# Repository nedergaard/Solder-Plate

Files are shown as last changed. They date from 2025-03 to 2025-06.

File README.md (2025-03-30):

🚀 This is a fork of [arwidcool/Solder-Plate](https://github.com/arwidcool/Solder-Plate). Please contribute to the original repository instead of this one.

---

# Solder Plate Controller with Detachable Hotplate

This repository contains the source code and design files for a Solder Plate Controller and detachable hotplate. The processor used is the ATmega4809 and is based on the work of DerSpatz. https://github.com/DerSpatz/PCB-reflow-solder-heat-plate

## Features
- Precise temperature control for soldering SMD components. with support of **up to 6 thermistors**.
- Cheap and widely available MCU- Atmega4809 and low BOM cost
- Custom PCB design with 2 versions: single area control (Completed) and 4 independent heating zones control(In works)
- Detacabale hotplate allows for use of new heatplate designs including larger ones
- Programming via USB
- PlatformIO integration for streamlined development.
- wifi via esp8266-12f module (with wifi version - In Development).
- Based on Reflow Hotplate by DerSpatz with some improvements
- Oled for menu navigation, debugging, and thermistor info
- TFT for reflow profile target and actual temp
- 4 buttons for menu navigation
- Current sense IC for current monitoring
- 3 indicator LED's. They work for both menu and REFLOW profiles (blinking while on the current stage and solid once the profile stage is complete).
- Buzzer for complete notification
- Buck- Converter for input voltage, allowing up to 24V in
- 24V+ rated input voltage stage components allowing  up to 24V to be used (Depending on powersupply trip option the "max" pwm needs to be lowered to not trip power suppply safety)
- Optional fan for cooling stage (not yet installed)
= Included are files for a case and a guard for the detachable plate terminal guard.





## Getting Started

### Prerequisites

- PlatformIO Core or PlatformIO IDE.
- ATmega4809 microcontroller and all the BOM components
- Basic soldering tools and electronic assembly skills.
- Access to a PCB manufacturing service or soldering equipment (solder paste, hot air gun, tweezers)
- Some basic technical skills

### Hardware Setup

*** MAKE SURE YOU ORDER THE HOTPLATE IN BLACK. IT WILL NOT DISCOLOR AND HOLDS UP A LOT BETTER TO HEAT CYCLES ***

1. **PCB Fabrication:** Fabricate the PCB using the provided gerber files. You can use these to order the naked PCB from services like JLCPCB. 
2. **Component Assembly:** Solder the components onto the PCB as per the schematic or choose a SMT assembly service like the ones from JLCPCB
3. **Power Supply Connection:** Choose a suitable power supply. 12V 5A tested, 24v 5A compatible. Use of more then 5A requires a appropriate FUSE to be chosen and solder on place of F1

### Preparing the ATmega4809

Before programming the ATmega4809, it needs to be flashed with a default bootloader.

1. **Bootloader Flashing:**

Same process as DerSpatz Solder plate with some changes to the bootloader settingffs:

The MCU can be programmed with JTAG2UPDI (https://github.com/ElTangas/jtag2updi). For programming, you need an Arduino with ATMEGA328p (Uno or Nano), some wires, a 4.7k resistor and a 10µF capacitor or 120 Ohm resistor to disable the auto-reset.

JCM from the Discord explained the process pretty good:

- Download/Clone this project: https://github.com/ElTangas/jtag2updi and rename the folder "source" to "jtag2updi" (otherwise the Arduino IDE won't like it)
- Open jtag2updi/jtag2updi.ino in your Arduino IDE
- Configure the flasher options for your Arduino Nano and flash it
- Connect D6 of your Arduino Nano over the 4.7kOhm resistor to the UPDI pin of the board and 5V to 5V and GND to 0V
- Add the MegaCoreX hardware package to the Ardunio IDE (see https://github.com/MCUdude/MegaCoreX#how-to-install)
- Select the options for the programmer **(Board: ATmega4809, Clock: Internal 16 MHz, BOD: 2.6V or 2.7V, EEPROM: retained, Pinout: 48 pin standard, Reset pin: Reset, Bootloader:Optiboot:Uart0(Defualt pins))** and select the port of your Ardunio Nano as Port
- Make sure the programmer selected is SerialUPDI or JTAG2UPDI
- Select Burn Bootloader and see if it runs through

2. **MicroUSB Programming And Firmware Upload:**

   - **Using Platformio:**
   1. After flashing the bootloader, the ATmega4809 can be programmed via the microUSB connection using PlatformIO by building the project and upload
  
   - **Using AVRDude:**
   1. Folow instructions on : https://github.com/ElTangas/jtag2updi?tab=readme-ov-file#using-with-avrdude
   2. Example : avrdude -c jtag2updi -P com7 -p t1614
  
   - **Using AVRDUDESS (AVRDUDE with GUI interface) -- This section many not be completley finished:**
   1. Download and install AVRDUDE https://download-mirror.savannah.gnu.org/releases/avrdude/
   2. Download AVRDUDESS : https://github.com/ZakKemble/AVRDUDESS
   3. Choose the programmer as arduino
   4. Choose the MCU as ATmega4809
   5. Choose the COMPORT where the Solder Plate Controller is connected to
   6. Choose the Flash binary in the programming directory -> set to Write
   7. Choose "Write" on the Flash option and press "Go"



3. **Setting up the controller**
   1. Order 100K NTC Glass thermistors  Use for dev was : 100K Ohm Resistor NTC 3950->  https://www.aliexpress.com/item/32862228715.html?spm=a2g0o.order_list.order_list_main.11.1f0a1802Lw8YGL
   2. Using either the potentiometer or soldering the resistor beside it choose the resistor reference value (2.5Kohm is standard)
   3. You can modify the thermistor settings in Global.ccp file, it is all explained in there
   4. Attach the sensors to the hotplate using High temp Kapton Tape
   5. Reccomended is 3 sensors on the bottom middle of plate all with 3 different refernece resistor values for accuracy across all temperature ranges and 1 thermistor held by a pair of helping hangs placed so the head touches somewhere on the PCB to be refllowed
   By default this is set as thermistor 1:
   6. Link to 2.0 inch TFT -> https://www.aliexpress.com/item/1005002363748586.html?spm=a2g0o.order_list.order_list_main.5.165d1802Amz1I7  (8 pin version) -> 7 Pin version can also be used 
   7. Link to 0.96 OLED -> https://www.aliexpress.com/item/32957309383.html?spm=a2g0o.order_list.order_list_main.17.662c1802iqqiSE  (Choose OLD design SSD1306)

   *** IMPORTANT: Thermistors 1 is ONLY available on the hotplate. Thermistor 6 is only available on the controller via connector 5**

   You can solder the thermistors directly on the hotplatte or use them with the connector. Please update the thermistor settings to the way you have them set-up.

   Here are the defualt thermistor settings, The assume that the thermistors are soldered on the plate for 1,2,3: 
   Thermistors 6 on the connector number 5, touching the PCB to be soldered.

   Thermistor thermistor1(THERMISTOR1_PIN, 2545, ThermistorZ_Placement::ON_PCB, ThermistorXY_Placement::MIDDLE);          // -> 2545ohm set refrence -> This thermistor is set directly touching the PCB to be soldered
   Thermistor thermistor2(THERMISTOR2_PIN, 9100, ThermistorZ_Placement::BOTTOM, ThermistorXY_Placement::MIDDLE_LOW_TEMP);          //- > 9100 ohm set refrence Best accuracy around 90C -> This thermistor is used for the lower end of the temp scale  
   Thermistor thermistor3(THERMISTOR3_PIN, 2040, ThermistorZ_Placement::BOTTOM, ThermistorXY_Placement::MIDDLE); // -> 2.5Kohm best middleground
   Thermistor thermistor4(THERMISTOR4_PIN, 564, ThermistorZ_Placement::BOTTOM, ThermistorXY_Placement::MIDDLE_HIGH_TEMP); //-> 564Kohm set refrence // 564R reference = Best accuracy around 210C

   If you wish to only use the connectors use 2,3,4 and update the Globals .cpp to match your settings
      
   The set resistence is measured between a GND point anywhere on the board and the LEFT pin of the connector with the thermistor UNPLUGGED and the MODULE POWERED OFF!!!!

   you can measure and set those to the preset values or modify the values in globals.ccp to match your thermistors.

   If a thermistor is set to bottom a automatic scaling factor for the difference difference in plate temp is set that was aquired through lots of datalogging and computations

   If a thermistor is set to SIDE there is no scaling factor and will throw off the reading acorss the center of the plate (overall will be lower)

   When using the Thermistor with placement "ON_PCB" That thermistor has a weighting factor of 10 and has the biggest effect on the read temperature.

   The normal weighting factor is between 0.1 and 1.5 for the others.

### Software Installation

1. **Clone the Repository:**
   ```bash
   git clone https://github.com/arwidcool/Solder-Plate
   cd Solder-Plate
2. **Import in vscode**
To open a PlatformIO project in VSCode with the PlatformIO extension, follow these steps:

1. Launch VSCode and ensure that you have the PlatformIO extension installed. If not, you can install it from the VSCode marketplace.
2. Open the VSCode command palette by pressing Ctrl+Shift+P (Windows/Linux) or Cmd+Shift+P (Mac).
3. In the command palette, type "PlatformIO: Open" and select the "PlatformIO: Open" command from the list.
4. Navigate to the root folder of your PlatformIO project using the file explorer that appears.
5. Select the folder and click "Open" to open the PlatformIO project in VSCode.

### Usage

Power On: Connect the controller with a 12V 5A(Tested working) or 24V 5A PSU (Untested)
Set Profile: Navigate the menu and choose the desired reflow profile
Start Soldering: Place your PCB and components on the hotplate and start the profile

### Customization

Feel free to modify the firmware and PCB design to suit your specific needs.

### Contributing
Contributions are welcome. Please follow standard procedures for contributing to open-source projects.

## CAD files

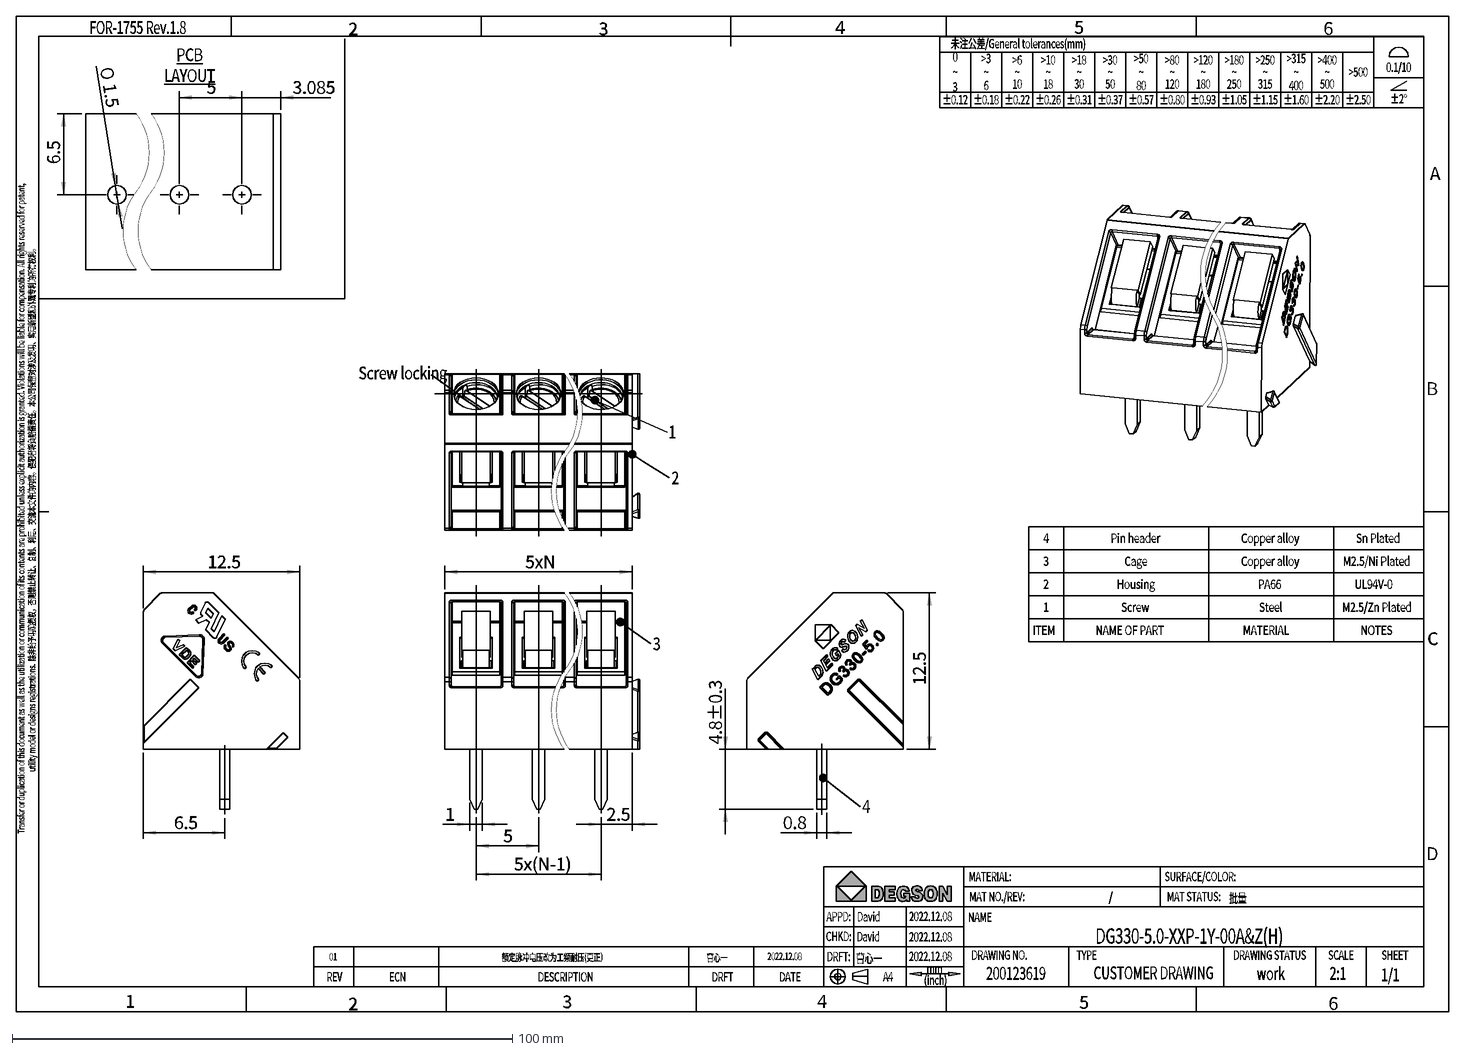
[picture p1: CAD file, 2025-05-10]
Hardware/1 Zone/KiCadWifi/DG330/DG330-5.0-XXP-1Y-00A&Z(H).dxf
4
Pin header
Copper alloy
Sn Plated
3
Cage
M2.5/Ni Plated
2
Housing
PA66
UL94V-0
1
Screw
Steel
M2.5/Zn Plated
ITEM
NAME OF PART
MATERIAL
NOTES
PCB LAYOUT
Screw locking
未注公差/General tolerances(mm)
0.1/10
0 ~ 3
>3 ~ 6
>6 ~ 10
>10 ~ 18
>18 ~ 30
>30 ~ 50
>50 ~ 80
>80 ~ 120
>120 ~ 180
>180 ~ 250
>250 ~ 315
>315 ~ 400
>400 ~ 500
>500
±2°
±0.12
±0.18
±0.22
±0.26
±0.31
±0.37
±0.57
±0.80
±0.93
±1.05
±1.15
±1.60
±2.20
±2.50
6.5
5
5x(N-1)
5xN
3.085
O
1.5
0.8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

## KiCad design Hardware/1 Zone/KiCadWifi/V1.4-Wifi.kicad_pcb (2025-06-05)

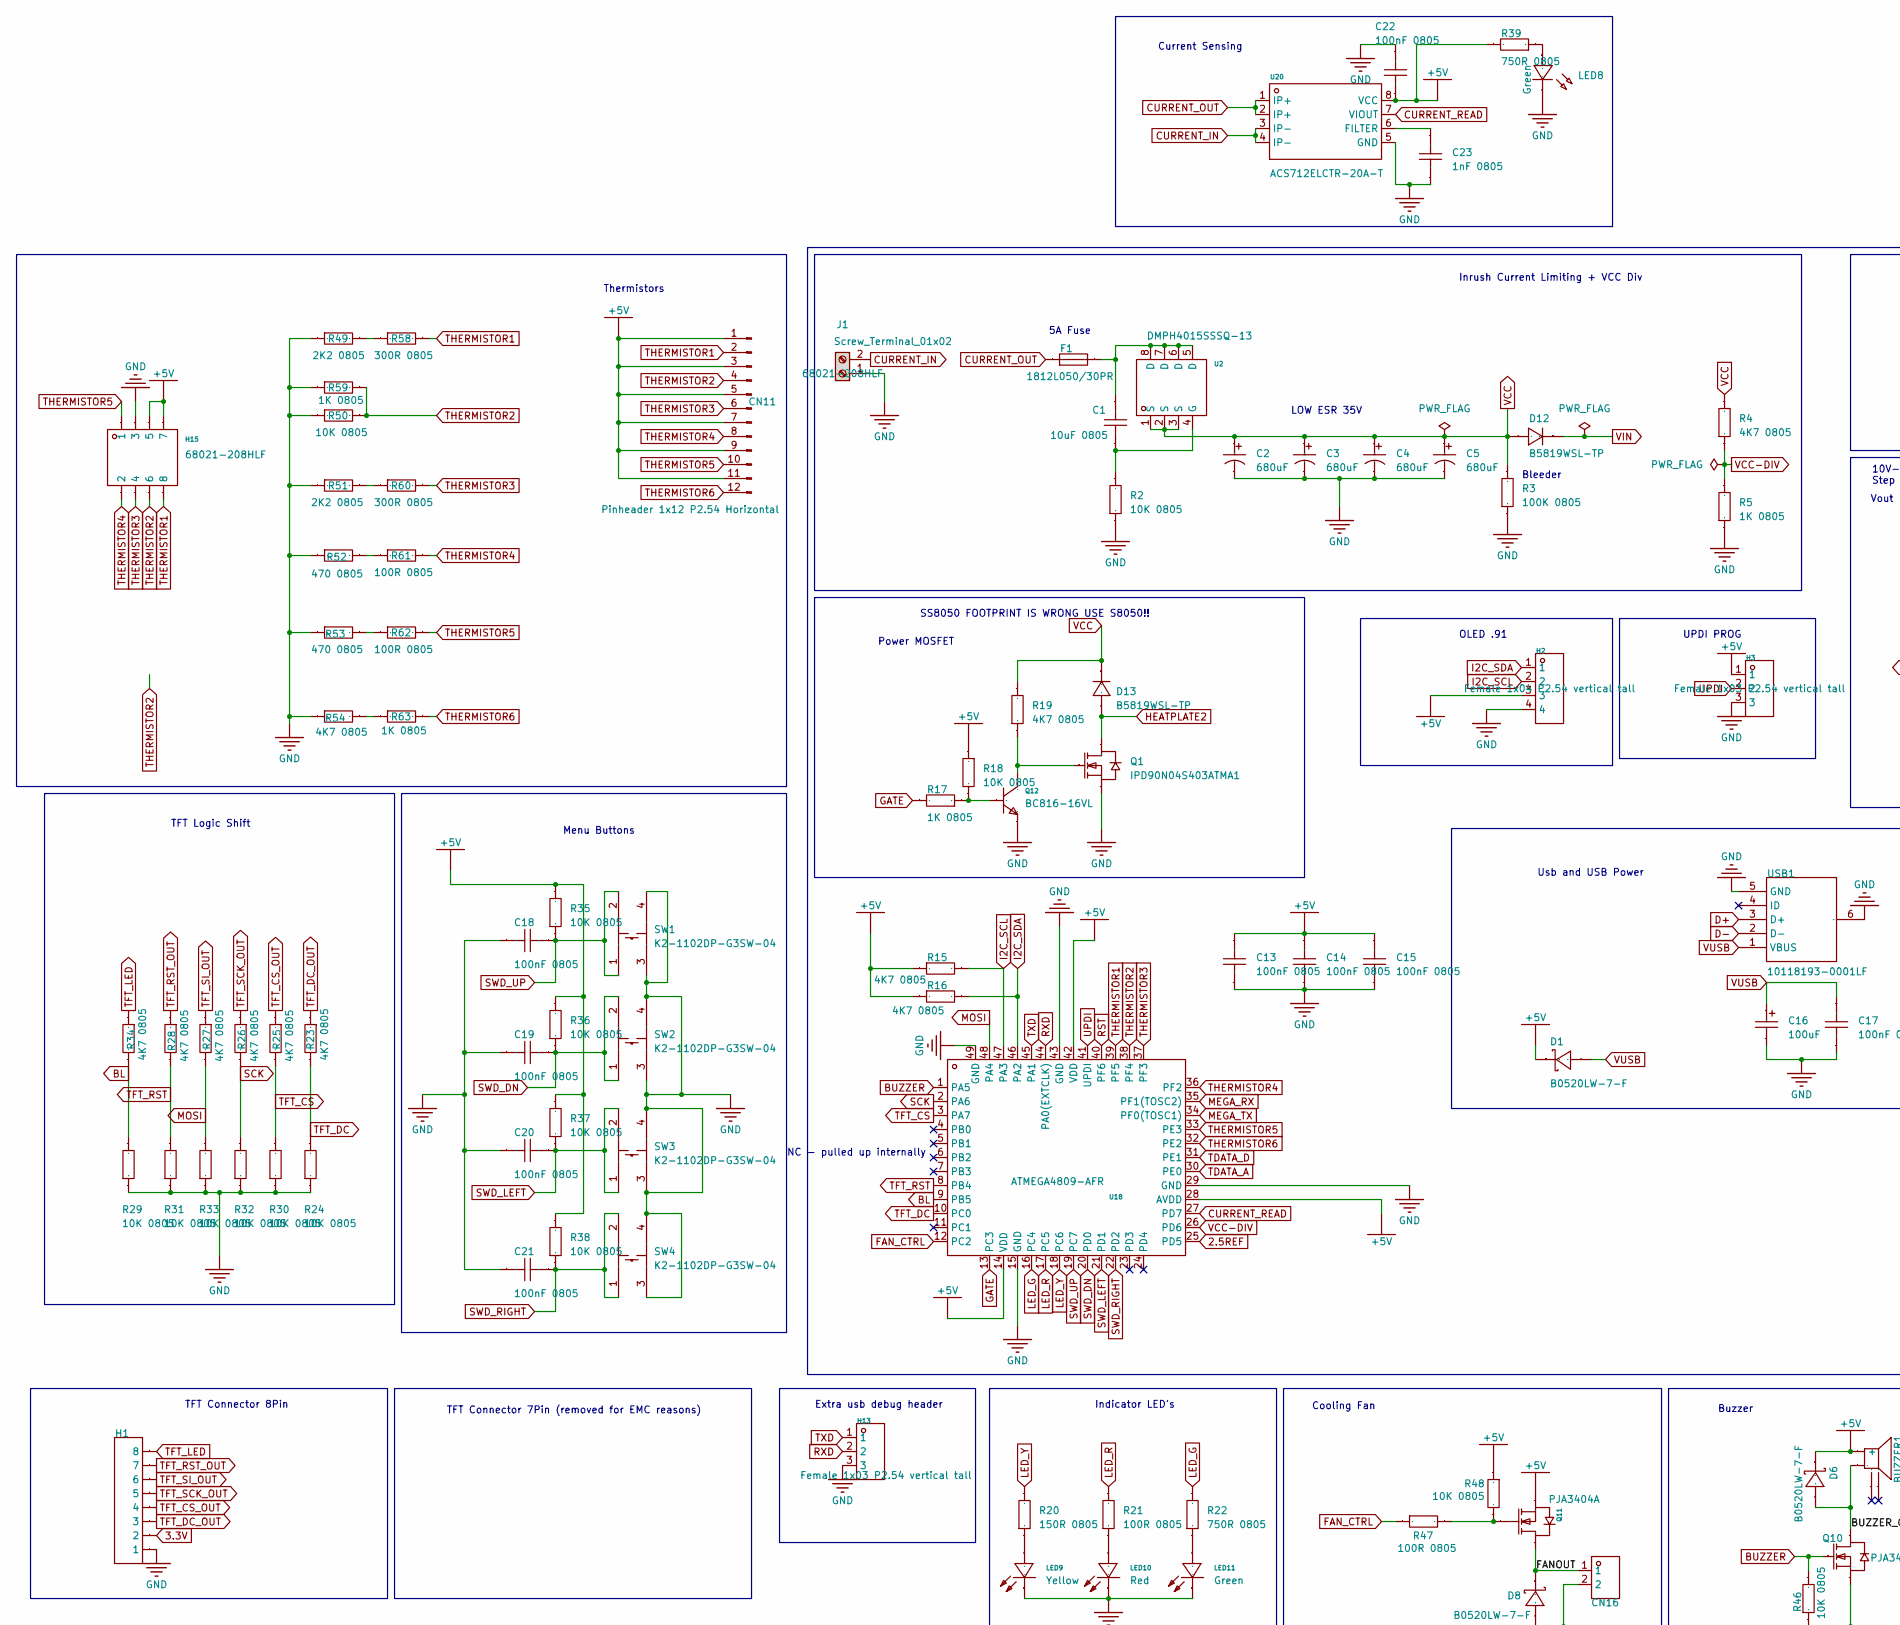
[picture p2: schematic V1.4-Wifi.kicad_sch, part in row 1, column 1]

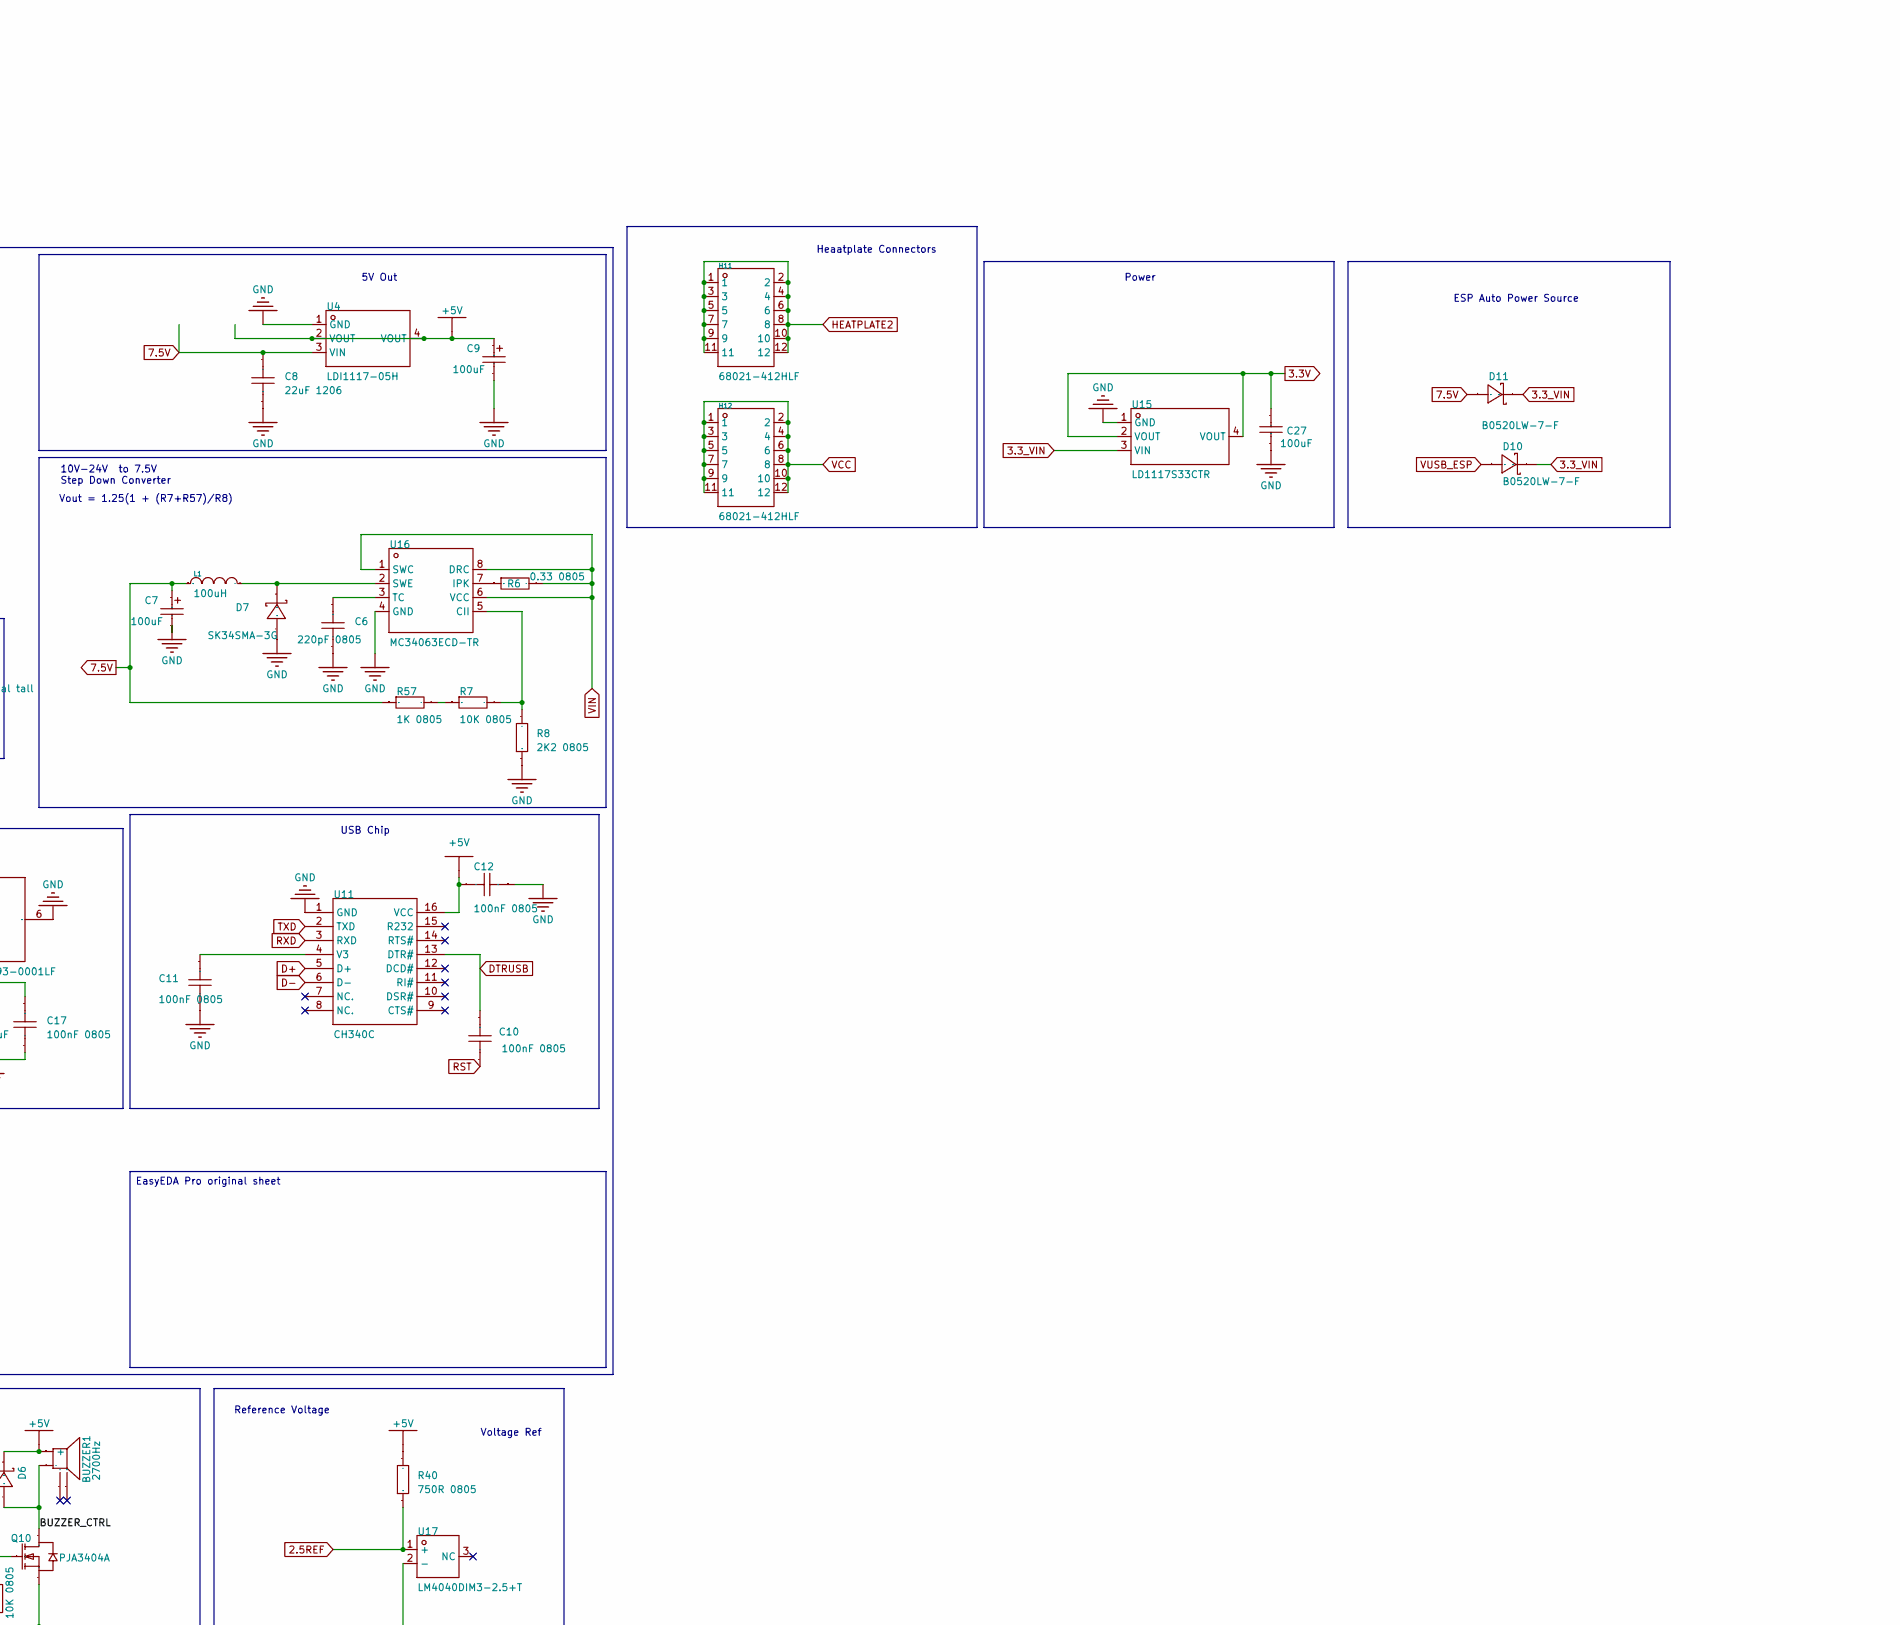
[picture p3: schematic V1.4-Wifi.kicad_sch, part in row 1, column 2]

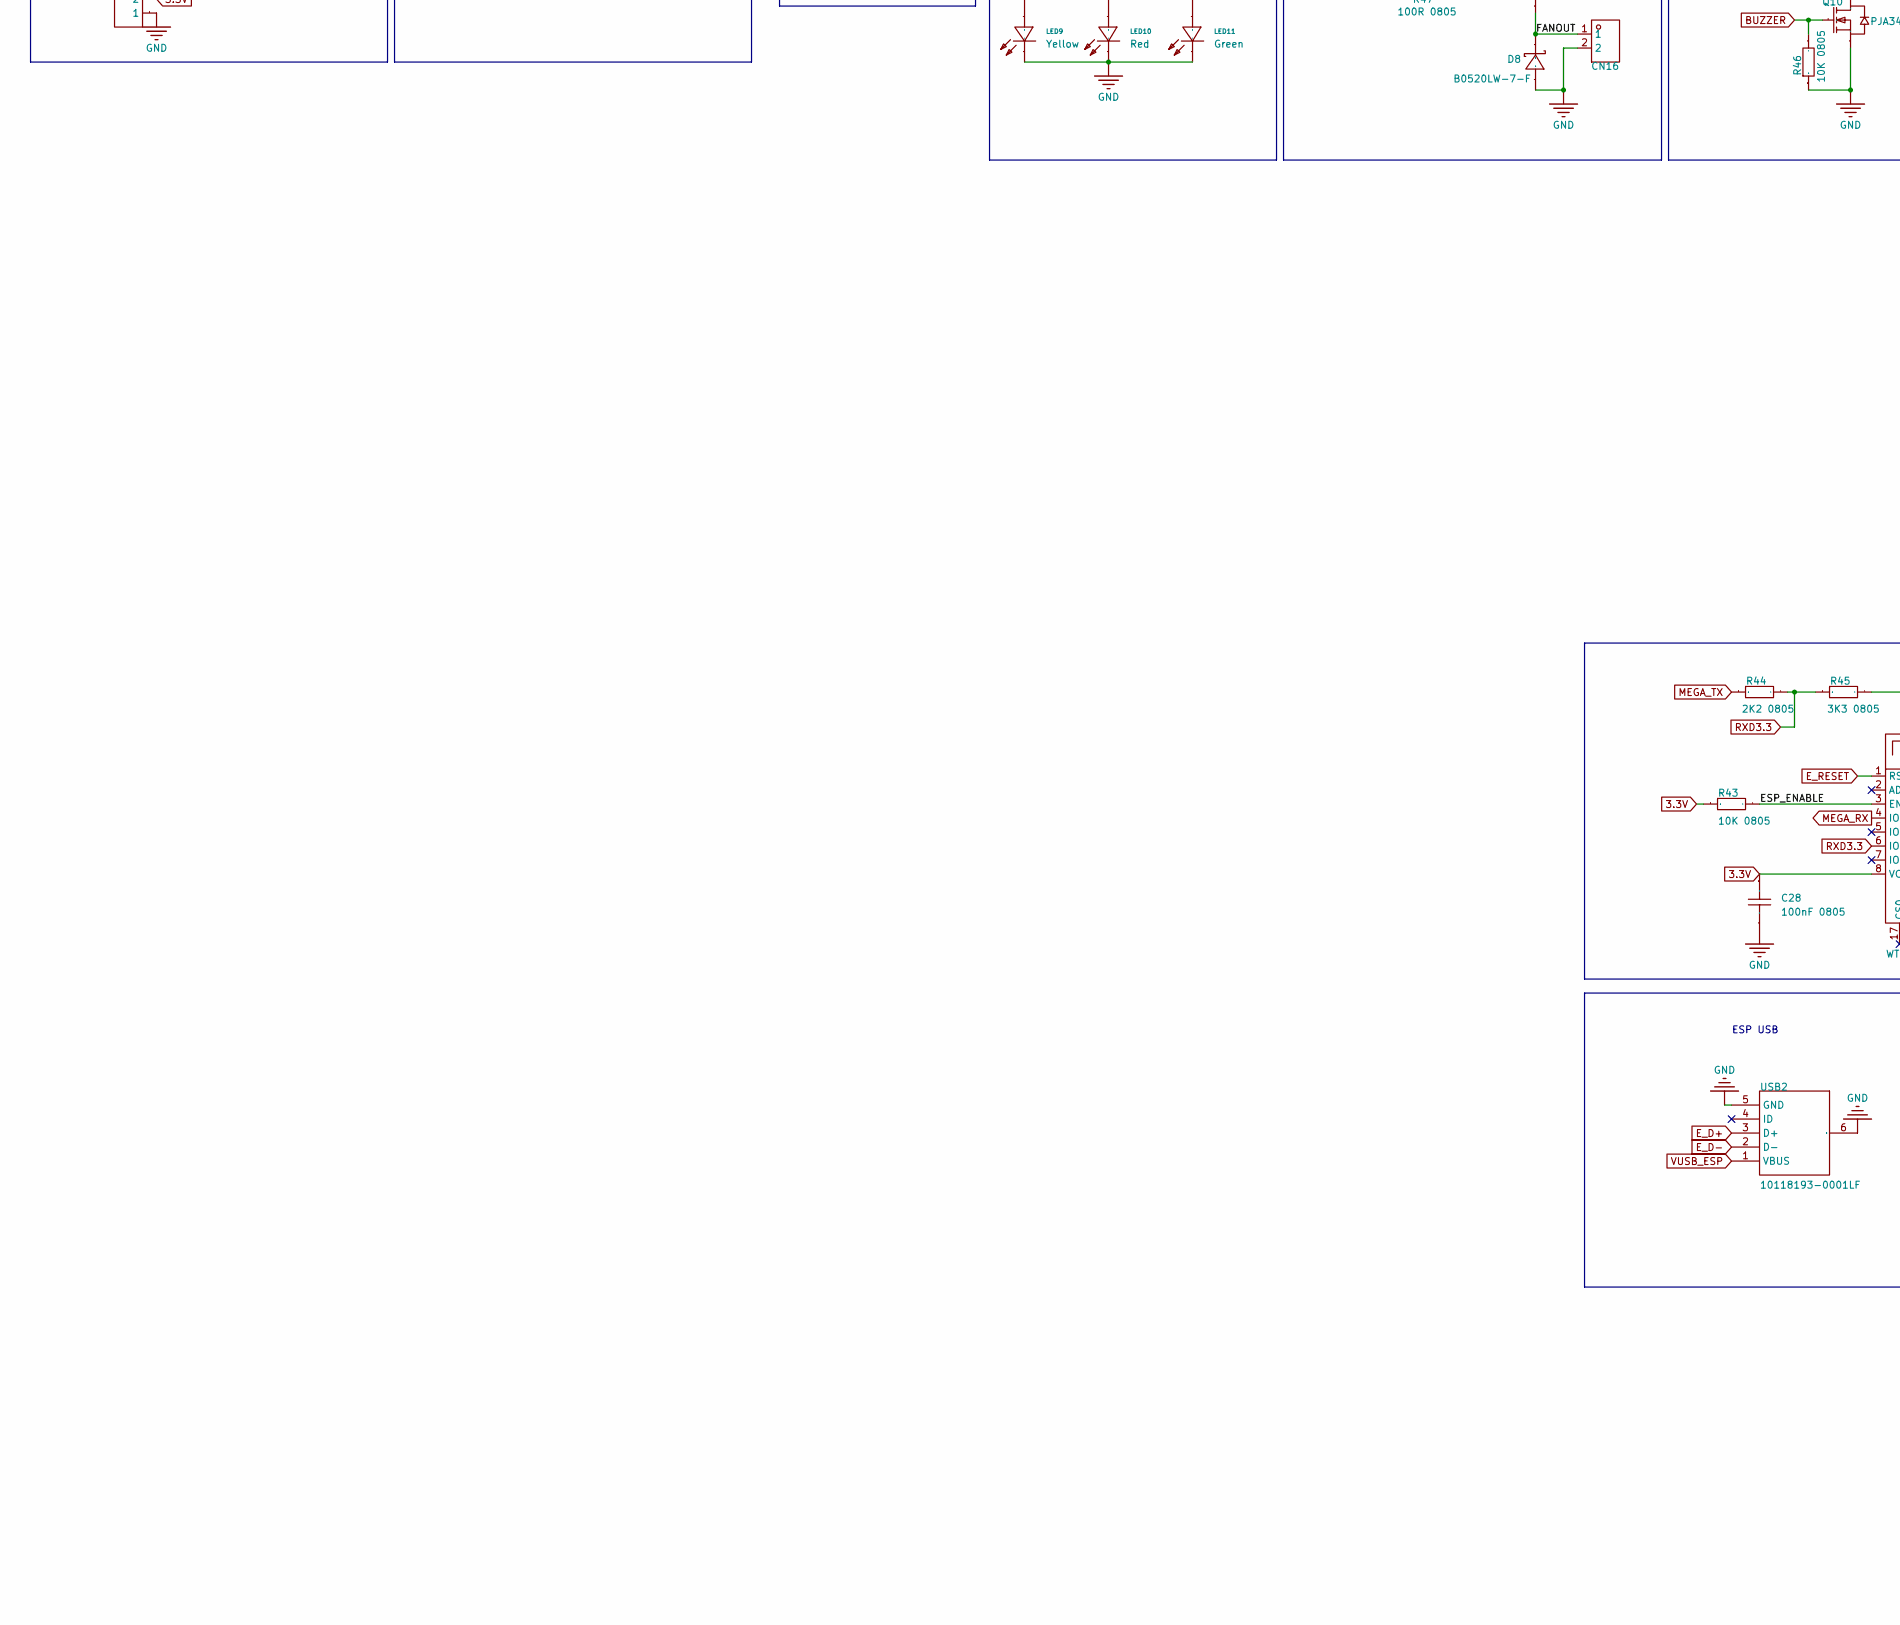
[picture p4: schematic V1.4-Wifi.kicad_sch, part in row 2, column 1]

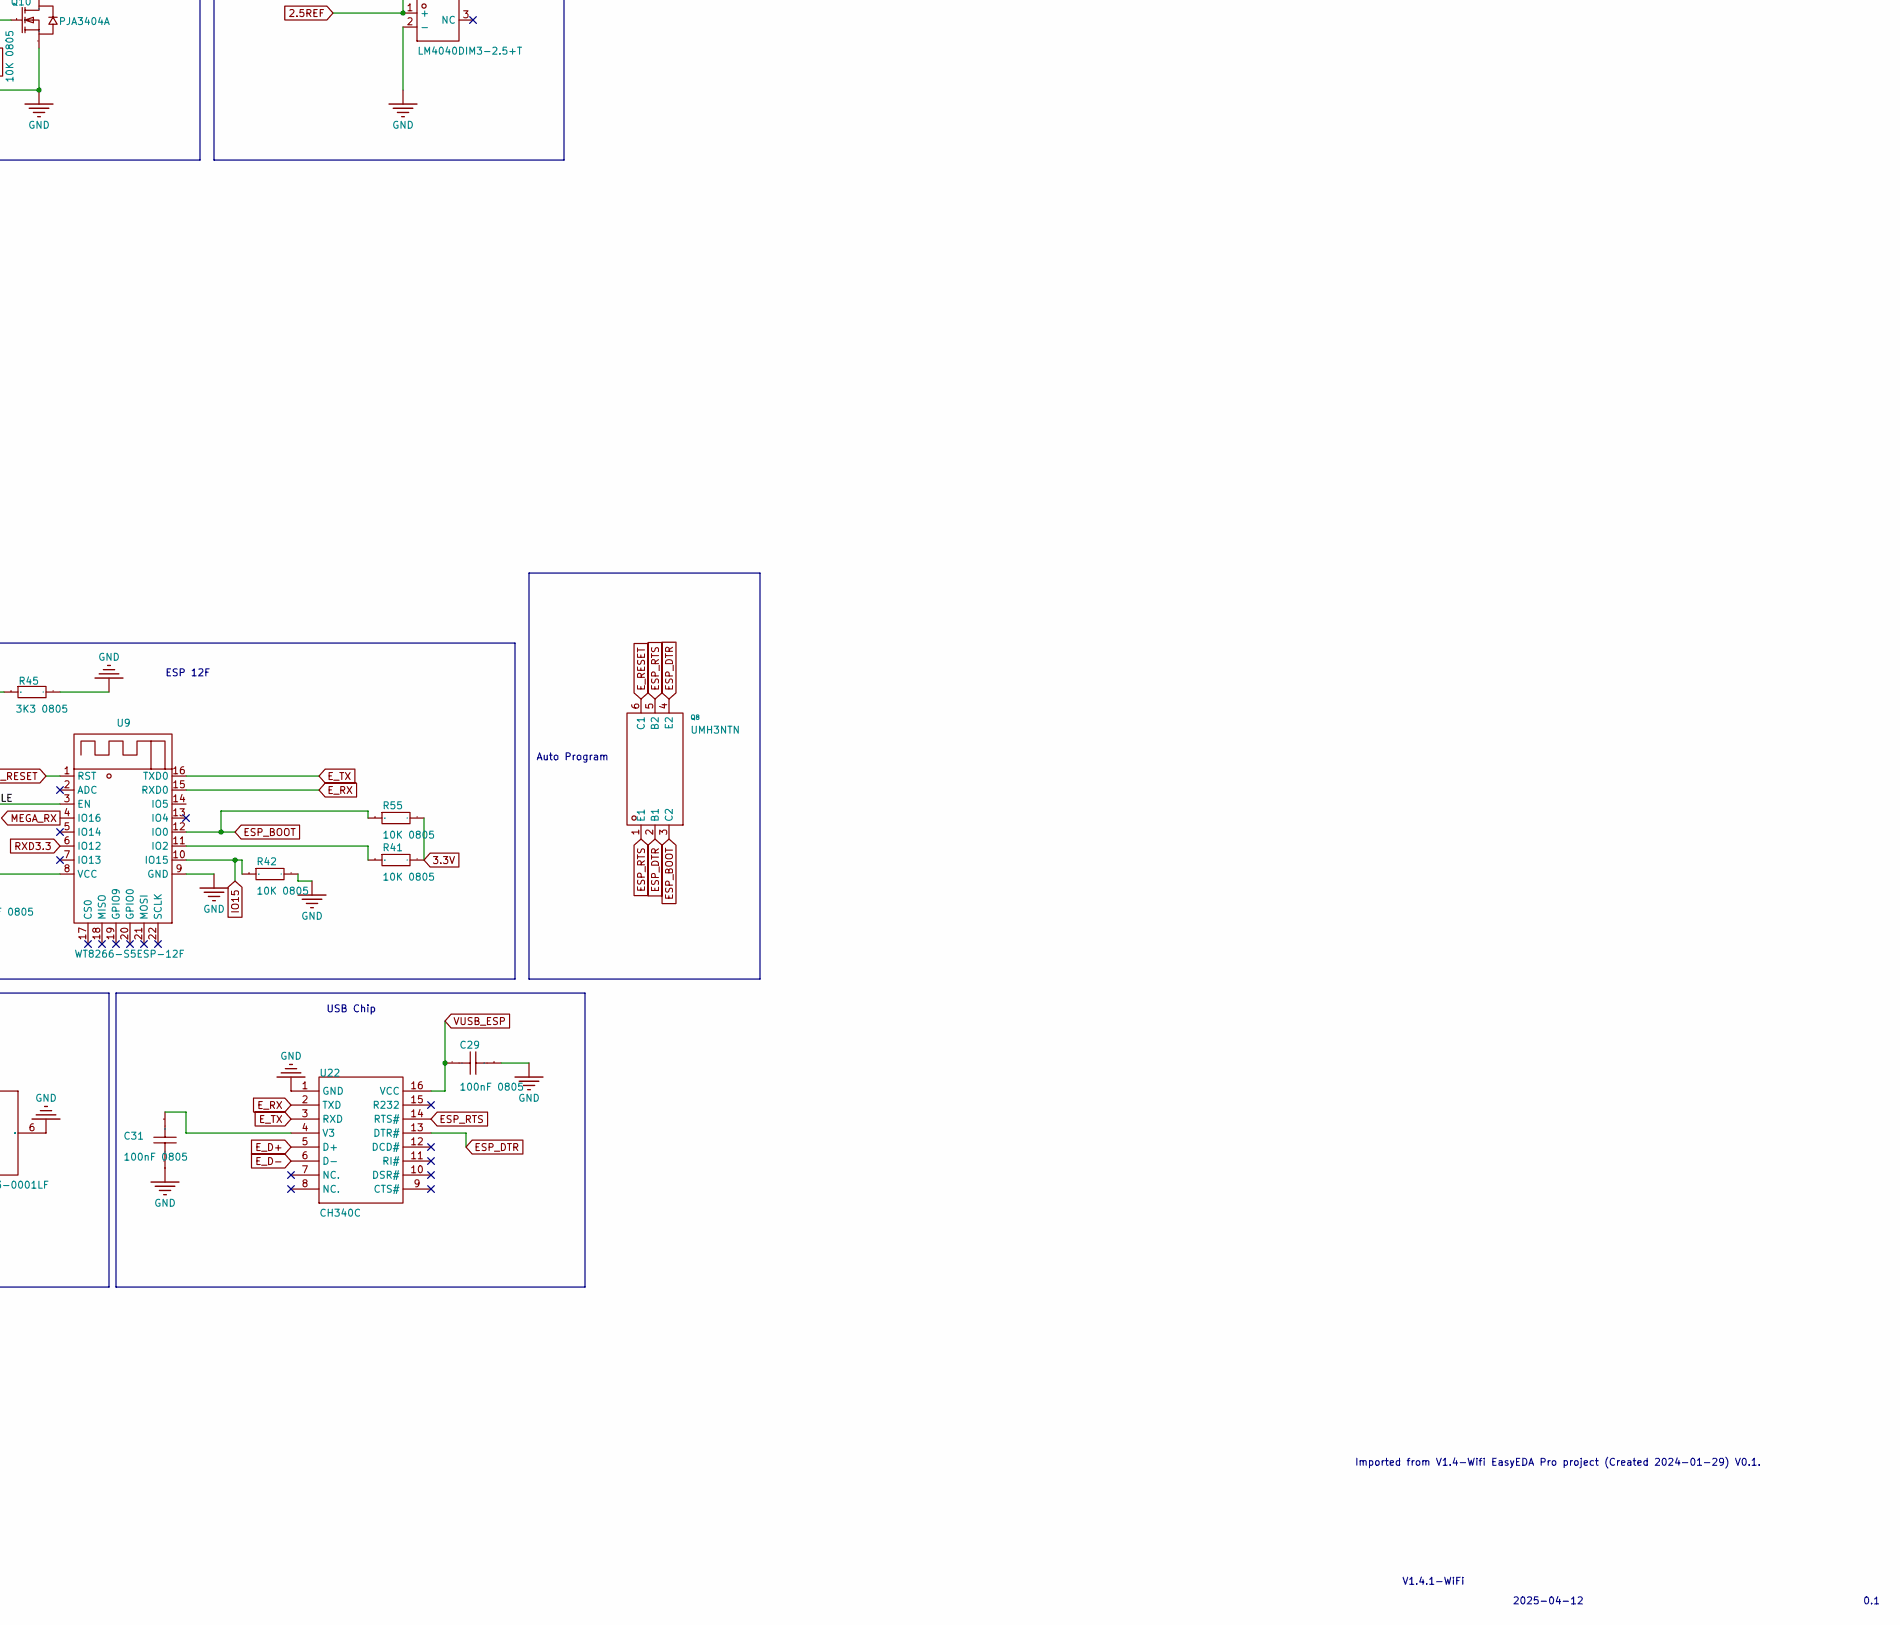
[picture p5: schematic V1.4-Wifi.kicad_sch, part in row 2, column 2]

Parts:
BUZZER1: 2700Hz; MagneticBuzzer_CUI_CMT-8504-100-SMT; mpn CMT-8530S-SMT-TRCMT-8504-100-SMT-TR
C1: 10uF 0805; C0805
C2, C3, C4, C5: 680uF; CP_Radial_D10.0mm_P5.00mm; mpn EEU-FR1V681B; LCSC Part Name 680uF±20%35V
C6: 220pF 0805; C0805
C7, C9, C16: 100uF; CAP-SMD_L3.5-W2.8-R-RD; mpn T491B107M010AT; LCSC Part Name 100uF ±20% 16V
C8: 22uF 1206; C_1206_3216Metric_Pad1.33x1.80mm_HandSolder
C10, C11, C12, C13, C14, C15, C17, C18, C19, C20, C21, C22, C28, C29, C31: 100nF 0805; C0805
C23: 1nF 0805; C0805
C27: 100uF; CAP-SMD_L3.5-W2.8-R-RD; mpn T491B107M010AT; LCSC Part Name 100uF±20%6.3V
CN11: Pinheader 1x12 P2.54 Horizontal; PinHeader_1x12_P2.54mm_Horizontal
CN16: Pinheader 1x02 P2.54 Horizontal; PinHeader_1x02_P2.54mm_Horizontal
D1, D6, D8, D10, D11: B0520LW-7-F; SOD-123_L2.8-W1.8-LS3.7-RD; mpn B0520LW-7-F; LCSC Part Name 20V500mA450mV@500mA
D7: SK34SMA-3G; D_SMA_Handsoldering; mpn SK34SMA-3G
D12, D13: B5819WSL-TP; D_SOD-323F; mpn B5819WSL-TP; LCSC Part Name B5819W
F1: 1812L050/30PR; Fuse_1812_4532Metric; mpn 1812L050/30PR; LCSC Part Name 5A
H1: Female 1x08 P2.54 vertical tall; HDR-TH_8P-P2.54-V-F-1
H2: Female 1x04 P2.54 vertical tall; HDR-TH_4P-P2.54-V-F; mpn 2.54-1*4P母; JLCPCB Part Class Extended Part
H3, H13: Female 1x03 P2.54 vertical tall; HDR-TH_3P-P2.54-V-F; mpn PM254V-11-03-H85; JLCPCB Part Class Extended Part
H11, H12: 68021-412HLF; HDR-TH_12P-P2.54-H-F-R2-C6-S2.54-W10.2; mpn 68021-412HLF; LCSC Part Name 2.54mm2x6P
H15: 68021-208HLF; HDR-TH_8P-P2.54-H-F-R2-C4-S2.54-W10.2; mpn A2541HWR-2x4P; LCSC Part Name 间距:2.54mm2x4P弯插
J1: Screw_Terminal_01x02; TerminalBlock_Phoenix_MKDS-1,5-2_1x02_P5.00mm_Horizontal; mpn 68021-208HLF
L1: 100uH; L_Coilcraft_MSS1048-XXX; mpn MSS1048-104MLC
LED8: Green; LED0805-RD_GREEN; mpn LTST-C171KGKT
LED9: Yellow; LED1206-RD; mpn LTST-C150YKT; LCSC Part Name 橙灯1206橙色正贴
LED10: Red; LED1206-RD; mpn LTST-C250KRKT; LCSC Part Name 橙灯1206橙色正贴
LED11: Green; LED1206-RD; mpn LTST-C150KGKT; LCSC Part Name 橙灯1206橙色正贴
Q1: IPD90N04S403ATMA1; TO-252-2_L6.6-W6.1-P4.57-LS9.9-TL-CW; mpn IPD90N04S403ATMA1; LCSC Part Name N沟道40V13A50A
Q8: UMH3NTN; SOT-363_L2.0-W1.3-P0.65-LS2.1-TL; mpn UMH3NTN; LCSC Part Name 电流:100mA耐压:50V
Q10: PJA3404A; SOT-23-3; mpn PJA3404A_R1_00001; LCSC Part Name N沟道20V4.2A
Q11: PJA3404A; SOT-23-3; mpn PJA3404A_R1_00001; LCSC Part Name N沟道耐压:20V电流:6A
Q12: BC816-16VL; SOT-23-3; mpn BC816-16VL; LCSC Part Name 电流:500mA 耐压:25V
R2, R7, R18, R24, R29, R30, R31, R32, R33, R35, R36, R37, R38, R41, R42, R43, R46, R48, R50, R55: 10K 0805; R_0805_2012Metric_Pad1.20x1.40mm_HandSolder
R3: 100K 0805; R_0805_2012Metric_Pad1.20x1.40mm_HandSolder
R4, R15, R16, R19, R23, R25, R26, R27, R28, R34, R54: 4K7 0805; R_0805_2012Metric_Pad1.20x1.40mm_HandSolder
R5, R17, R57, R59, R63: 1K 0805; R_0805_2012Metric_Pad1.20x1.40mm_HandSolder
R6: 0.33 0805; R_0805_2012Metric_Pad1.20x1.40mm_HandSolder; mpn KRL1220E-M-R330-F
R8, R44, R49, R51: 2K2 0805; R_0805_2012Metric_Pad1.20x1.40mm_HandSolder
R20: 150R 0805; R_0805_2012Metric_Pad1.20x1.40mm_HandSolder
R21, R47, R61, R62: 100R 0805; R_0805_2012Metric_Pad1.20x1.40mm_HandSolder
R22, R39, R40: 750R 0805; R_0805_2012Metric_Pad1.20x1.40mm_HandSolder
R45: 3K3 0805; R_0805_2012Metric_Pad1.20x1.40mm_HandSolder
R52, R53: 470 0805; R_0805_2012Metric_Pad1.20x1.40mm_HandSolder
R58, R60: 300R 0805; R_0805_2012Metric_Pad1.20x1.40mm_HandSolder
SW1, SW2, SW3, SW4: K2-1102DP-G3SW-04; KEY-TH_4P-L6.0-W6.0-P4.50-LS6.5; mpn K2-1102DP-G3SW-04; LCSC Part Name 6*6*7
U2: DMPH4015SSSQ-13; SOIC-8_3.9x4.9mm_P1.27mm
U4: LDI1117-05H; SOT-223
U9: WT8266-S5ESP-12F; WIFIM-SMD_22P-L24.0-W16.0-P2.00; mpn WT8266-S5ESP-12F
U11, U22: CH340C; SOP-16_L10.0-W3.9-P1.27-LS6.0-BL; mpn CH340C; LCSC Part Name CH340C
U15: LD1117S33CTR; SOT-223
U16: MC34063ECD-TR; SOIC-8_3.9x4.9mm_P1.27mm; mpn MC34063ECD-TR; LCSC Part Name 升降压型Vin=3V~40VVout=1.25V~38V1.5A
U17: LM4040DIM3-2.5+T; SOT-23-3; mpn LM4040DIM3-2.5+T; LCSC Part Name LM4040DIM3-2.5+T
U18: ATMEGA4809-AFR; TQFP-48-1EP_7x7mm_P0.5mm_EP3.5x3.5mm; mpn ATMEGA4809-AFR
U20: ACS712ELCTR-20A-T; SOIC-8_L4.9-W3.9-P1.27-LS6.0-BL; mpn ACS712ELCTR-20A-T; LCSC Part Name ACS712ELCTR-20A-T
USB1: 10118193-0001LF; USB_Micro-B_Amphenol_10118193-0001LF_Horizontal; mpn 10118193-0001LF
USB2: 10118193-0001LF; USB_Micro-B_Amphenol_10118193-0001LF_Horizontal; mpn 10118193-0001LF; LCSC Part Name Micro-B母座卧贴

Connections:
2.5REF: R40.1, U17.1 (+), U18.25 (PD5)
3.3V: C27.2, C28.1, H1.2, R41.2, R43.1, R55.2, U9.8 (VCC), U15.2 (VOUT), U15.4 (VOUT)
3.3_VIN: D10.1 (K), D11.1 (K), U15.3 (VIN)
7.5V: C7.1, C8.2, D11.2 (A), L1.1, R57.1, U4.3 (VIN)
+5V: BUZZER1.1 (+), C9.1, C12.2, C13.1, C14.1, C15.1, C22.2, CN11.1, CN11.3, CN11.5, CN11.7, CN11.9, CN11.11, D1.1 (K), D6.1 (K), H2.3, H3.1, H15.5, H15.7, Q11.2 (S), R15.1, R16.1, R18.1, R35.2, R36.2, R37.2, R38.2, R39.2, R40.2, R48.1, U4.2 (VOUT), U4.4 (VOUT), U11.16 (VCC), U18.14 (VDD), U18.28 (AVDD), U18.42 (VDD), U20.8 (VCC)
/BUZZER_CTRL: BUZZER1.2, D6.2 (A), Q10.3 (D)
/ESP_ENABLE: R43.2, U9.3 (EN)
/FANOUT: CN16.1, D8.1 (K), Q11.3 (D)
BL: R29.2, R34.2, U18.9 (PB5)
BUZZER: Q10.1 (G), R46.2, U18.1 (PA5)
CURRENT_IN: J1.2, U20.3 (IP-), U20.4 (IP-)
CURRENT_OUT: F1.1, U20.1 (IP+), U20.2 (IP+)
CURRENT_READ: U18.27 (PD7), U20.7 (VIOUT)
D+: U11.5 (D+), USB1.3 (D+)
D-: U11.6 (D-), USB1.2 (D-)
DTRUSB: C10.1, U11.13 (DTR#)
ESP_BOOT: Q8.3 (C2), R55.1, U9.12 (IO0)
ESP_DTR: Q8.2 (B1), Q8.4 (E2), U22.13 (DTR#)
ESP_RTS: Q8.1 (E1), Q8.5 (B2), U22.14 (RTS#)
E_D+: U22.5 (D+), USB2.3 (D+)
E_D-: U22.6 (D-), USB2.2 (D-)
E_RESET: Q8.6 (C1), U9.1 (RST)
E_RX: U9.15 (RXD0), U22.2 (TXD)
E_TX: U9.16 (TXD0), U22.3 (RXD)
FAN_CTRL: R47.1, U18.12 (PC2)
GATE: R17.2, U18.13 (PC3)
GND: C2.2, C3.2, C4.2, C5.2, C6.2, C7.2, C8.1, C9.2, C11.2, C12.1, C13.2, C14.2, C15.2, C16.2, C17.2, C18.2, C19.2, C20.2, C21.2, C22.1, C23.2, C27.1, C28.2, C29.1, C31.2, CN16.2, D7.2 (A), D8.2 (A), H1.1, H2.4, H3.3, H13.3, H15.3, J1.1, LED8.2 (C), LED9.1 (-), LED10.1 (-), LED11.1 (-), Q1.3 (S), Q10.2 (S), Q12.2 (E), R2.1, R3.1, R5.1, R8.1, R24.1, R29.1, R30.1, R31.1, R32.1, R33.1, R42.2, R45.2, R46.1, R49.1, R50.1, R51.1, R52.1, R53.1, R54.1, R59.1, SW1.3, SW1.4, SW2.3, SW2.4, SW3.3, SW3.4, SW4.3, SW4.4, U4.1 (GND), U9.9 (GND), U11.1 (GND), U15.1 (GND), U16.4 (GND), U17.2 (-), U18.15 (GND), U18.29 (GND), U18.43 (GND), U18.49 (GND), U20.5 (GND), U22.1 (GND), USB1.5 (GND), USB1.6 (EH), USB2.5 (GND), USB2.6 (EH)
HEATPLATE2: D13.2, H11.1, H11.2, H11.3, H11.4, H11.5, H11.6, H11.7, H11.8, H11.9, H11.10, H11.11, H11.12, Q1.2 (D)
I2C_SCL: H2.2, R15.2, U18.47 (PA3)
I2C_SDA: H2.1, R16.2, U18.46 (PA2)
IO15: R42.1, U9.10 (IO15)
LED_G: R22.2, U18.16 (PC4)
LED_R: R21.2, U18.17 (PC5)
LED_Y: R20.2, U18.18 (PC6)
MEGA_RX: U9.4 (IO16), U18.35 (PF1(TOSC2))
MEGA_TX: R44.1, U18.34 (PF0(TOSC1))
MOSI: R27.2, R33.2, U18.48 (PA4)
unnamed: C1.1, F1.2, U2.5 (D), U2.6 (D), U2.7 (D), U2.8 (D)
unnamed: D7.1 (K), L1.2, U16.2 (SWE)
unnamed: LED8.1 (A), R39.1
unnamed: LED9.2 (+), R20.1
unnamed: LED10.2 (+), R21.1
unnamed: LED11.2 (+), R22.1
unnamed: Q1.1 (G), Q12.3 (C), R19.1
unnamed: Q11.1 (G), R47.2, R48.2
unnamed: Q12.1 (B), R17.1, R18.2
unnamed: R49.2, R58.1
unnamed: R51.2, R60.1
unnamed: R52.2, R61.1
unnamed: R53.2, R62.1
unnamed: R54.2, R63.1
unnamed: R7.1, R57.2
unnamed: C1.2, R2.2, U2.4 (G)
unnamed: R41.1, U9.11 (IO2)
unnamed: C11.1, U11.4 (V3)
unnamed: R7.2, R8.2, U16.5 (CII)
unnamed: R6.1, U16.7 (IPK)
unnamed: C6.1, U16.3 (TC)
unnamed: C23.1, U20.6 (FILTER)
unnamed: C31.1, U22.4 (V3)
RST: C10.2, U18.40 (PF6)
RXD: H13.2, U11.3 (RXD), U18.44 (PA0(EXTCLK))
RXD3.3: R44.2, R45.1, U9.6 (IO12)
SCK: R26.2, R32.2, U18.2 (PA6)
SWD_DN: C19.1, R36.1, SW2.1, SW2.2, U18.20 (PD0)
SWD_LEFT: C20.1, R37.1, SW3.1, SW3.2, U18.21 (PD1)
SWD_RIGHT: C21.1, R38.1, SW4.1, SW4.2, U18.22 (PD2)
SWD_UP: C18.1, R35.1, SW1.1, SW1.2, U18.19 (PC7)
TDATA_A: U18.30 (PE0)
TDATA_D: U18.31 (PE1)
TFT_CS: R25.2, R30.2, U18.3 (PA7)
TFT_CS_OUT: H1.4, R25.1
TFT_DC: R23.2, R24.2, U18.10 (PC0)
TFT_DC_OUT: H1.3, R23.1
TFT_LED: H1.8, R34.1
TFT_RST: R28.2, R31.2, U18.8 (PB4)
TFT_RST_OUT: H1.7, R28.1
TFT_SCK_OUT: H1.5, R26.1
TFT_SI_OUT: H1.6, R27.1
THERMISTOR1: CN11.2, H15.8, R58.2, U18.39 (PF5)
THERMISTOR2: CN11.4, H15.6, R50.2, R59.2, U18.38 (PF4)
THERMISTOR3: CN11.6, H15.4, R60.2, U18.37 (PF3)
THERMISTOR4: CN11.8, H15.2, R61.2, U18.36 (PF2)
THERMISTOR5: CN11.10, H15.1, R62.2, U18.33 (PE3)
THERMISTOR6: CN11.12, R63.2, U18.32 (PE2)
TXD: H13.1, U11.2 (TXD), U18.45 (PA1)
UPDI: H3.2, U18.41 (UPDI)
VCC: C2.1, C3.1, C4.1, C5.1, D12.2, D13.1, H12.1, H12.2, H12.3, H12.4, H12.5, H12.6, H12.7, H12.8, H12.9, H12.10, H12.11, H12.12, R3.2, R4.2, R19.2, U2.1 (S), U2.2 (S), U2.3 (S)
VCC-DIV: R4.1, R5.2, U18.26 (PD6)
VIN: D12.1, R6.2, U16.1 (SWC), U16.6 (VCC), U16.8 (DRC)
VUSB: C16.1, C17.1, D1.2 (A), USB1.1 (VBUS)
VUSB_ESP: C29.2, D10.2 (A), U22.16 (VCC), USB2.1 (VBUS)

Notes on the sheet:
Thermistors
Extra usb debug header
Menu Buttons
UPDI PROG
SS8050 FOOTPRINT IS WRONG USE S8050!!
USB Chip
NC - pulled up internally
Auto Program
Vout = 1.25(1 + (R7+R57)/R8)
10V-24V to 7.5V Step Down Converter
Buzzer
TFT Connector 7Pin (removed for EMC reasons)
Bleeder
ESP Auto Power Source
Power
ESP USB
Cooling Fan
Usb and USB Power
TFT Logic Shift
Voltage Ref
2025-04-12
OLED .91
Power MOSFET
LOW ESR 35V
Current Sensing
V1.4.1-WiFi
5A Fuse
0.1
TFT Connector 8Pin
Reference Voltage
Heaatplate Connectors
Inrush Current Limiting + VCC Div
5V Out
Indicator LED's
Imported from V1.4-Wifi EasyEDA Pro project (Created 2024-01-29) V0.1.
ESP 12F
EasyEDA Pro original sheet

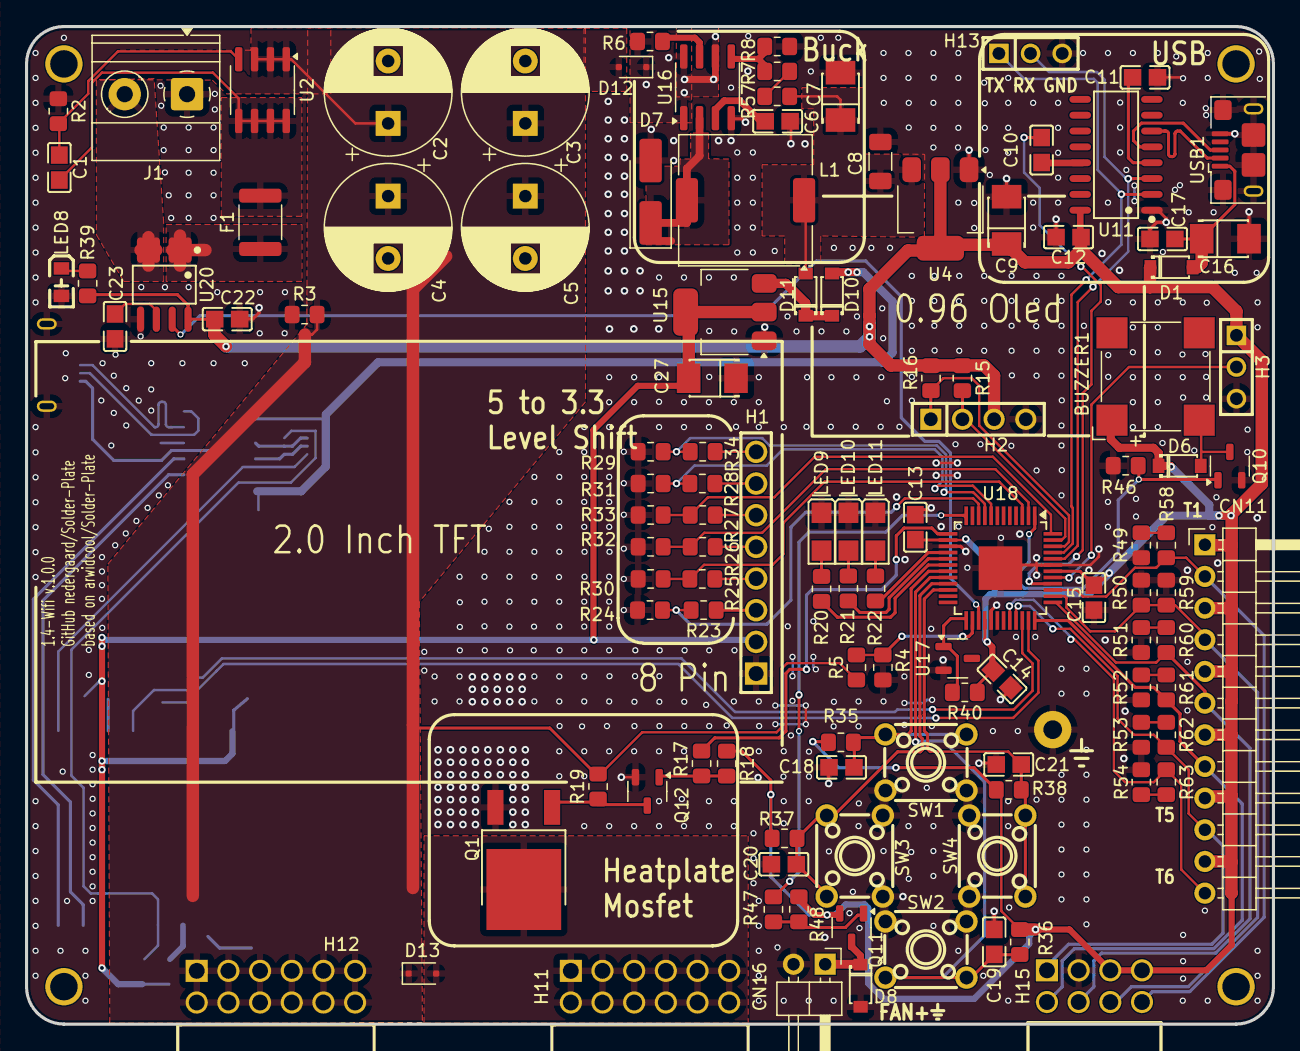
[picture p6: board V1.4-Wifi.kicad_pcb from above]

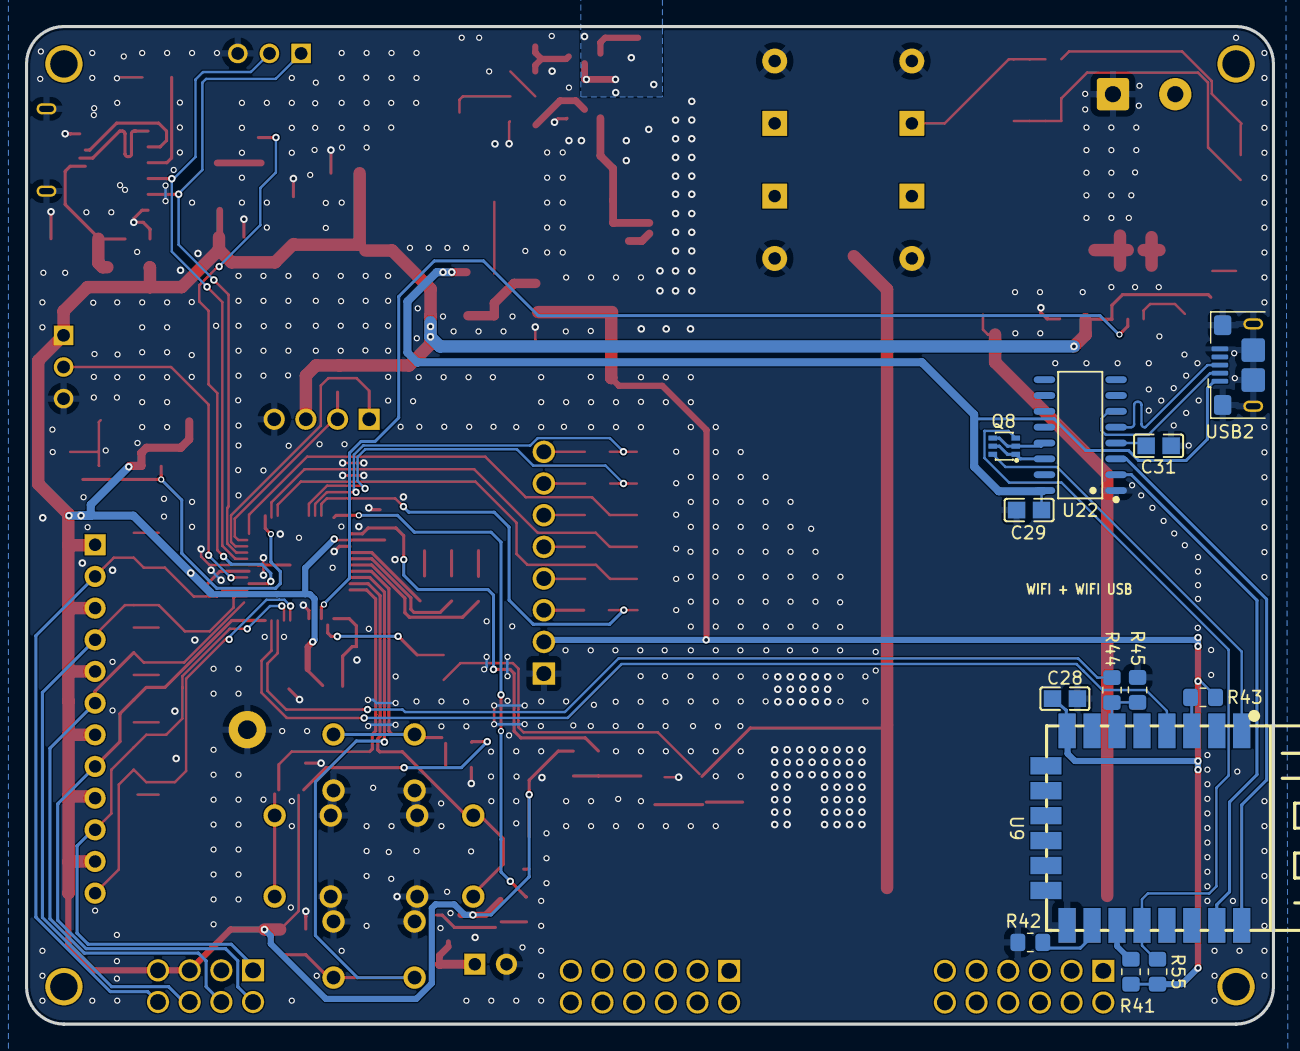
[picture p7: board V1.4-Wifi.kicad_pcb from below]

Board: 2 copper layers, 100.0 x 80.0 mm, 128 parts (13 on the bottom side), 90 nets.

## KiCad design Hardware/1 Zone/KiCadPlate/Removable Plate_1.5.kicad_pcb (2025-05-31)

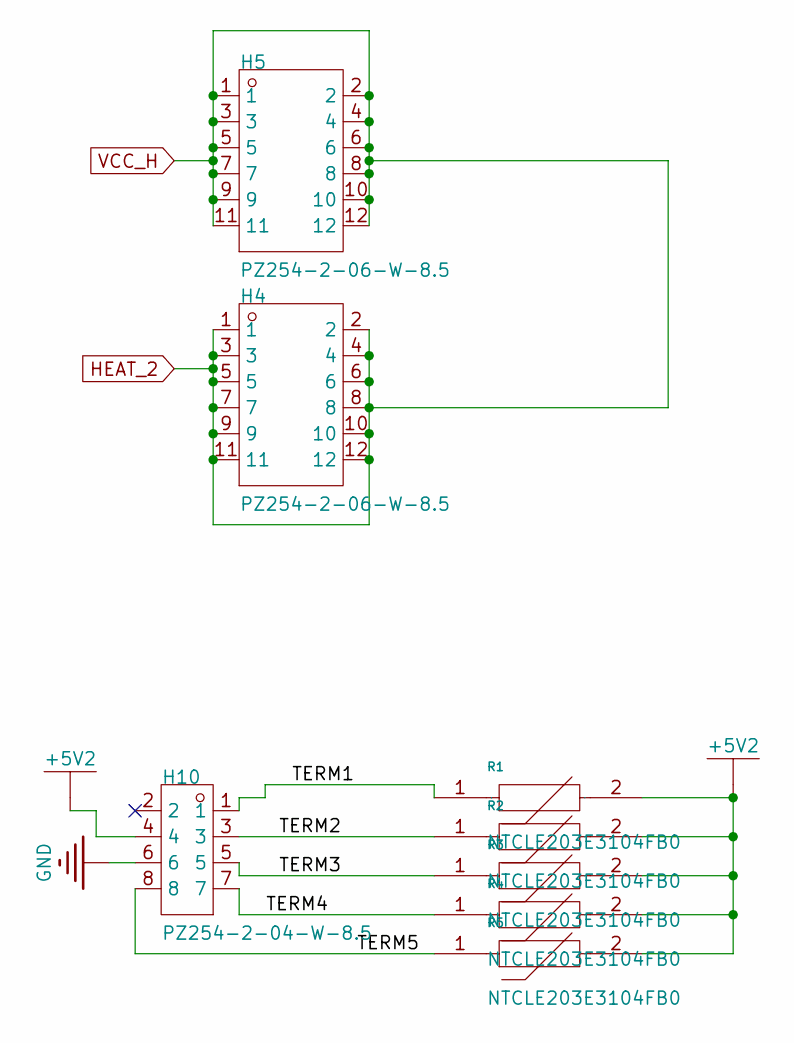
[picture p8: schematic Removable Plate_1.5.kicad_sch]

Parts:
H4, H5: PZ254-2-06-W-8.5; HDR-TH_12P-P2.54-H-M-R2-C6-S2.54-N; Manufacturer Part PZ254-2-06-W-8.5; LCSC Part Name 2.54mm2x6P弯插方针
H10: PZ254-2-04-W-8.5; HDR-TH_8P-P2.54-H-M-R2-C4-S2.54-N; Manufacturer Part PZ254-2-04-W-8.5; LCSC Part Name 2.54mm2x4P弯插方针
R1, R2, R3, R4, R5: NTCLE203E3104FB0; PinHeader_1x02_P2.54mm_Vertical; Manufacturer Part NTCLE203E3104FB0; LCSC Part Name 100kΩ电阻精度:±1%

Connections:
+5V2: H10.4, R1.2, R2.2, R3.2, R4.2, R5.2
/TERM1: H10.1, R1.1
/TERM2: H10.3, R2.1
/TERM3: H10.5, R3.1
/TERM4: H10.7, R4.1
/TERM5: H10.8, R5.1
GND: H10.6
HEAT_2: H4.1, H4.2, H4.3, H4.4, H4.5, H4.6, H4.7, H4.8, H4.9, H4.10, H4.11, H4.12, H5.1, H5.2, H5.3, H5.4, H5.5, H5.6, H5.7, H5.8, H5.9, H5.10, H5.11, H5.12

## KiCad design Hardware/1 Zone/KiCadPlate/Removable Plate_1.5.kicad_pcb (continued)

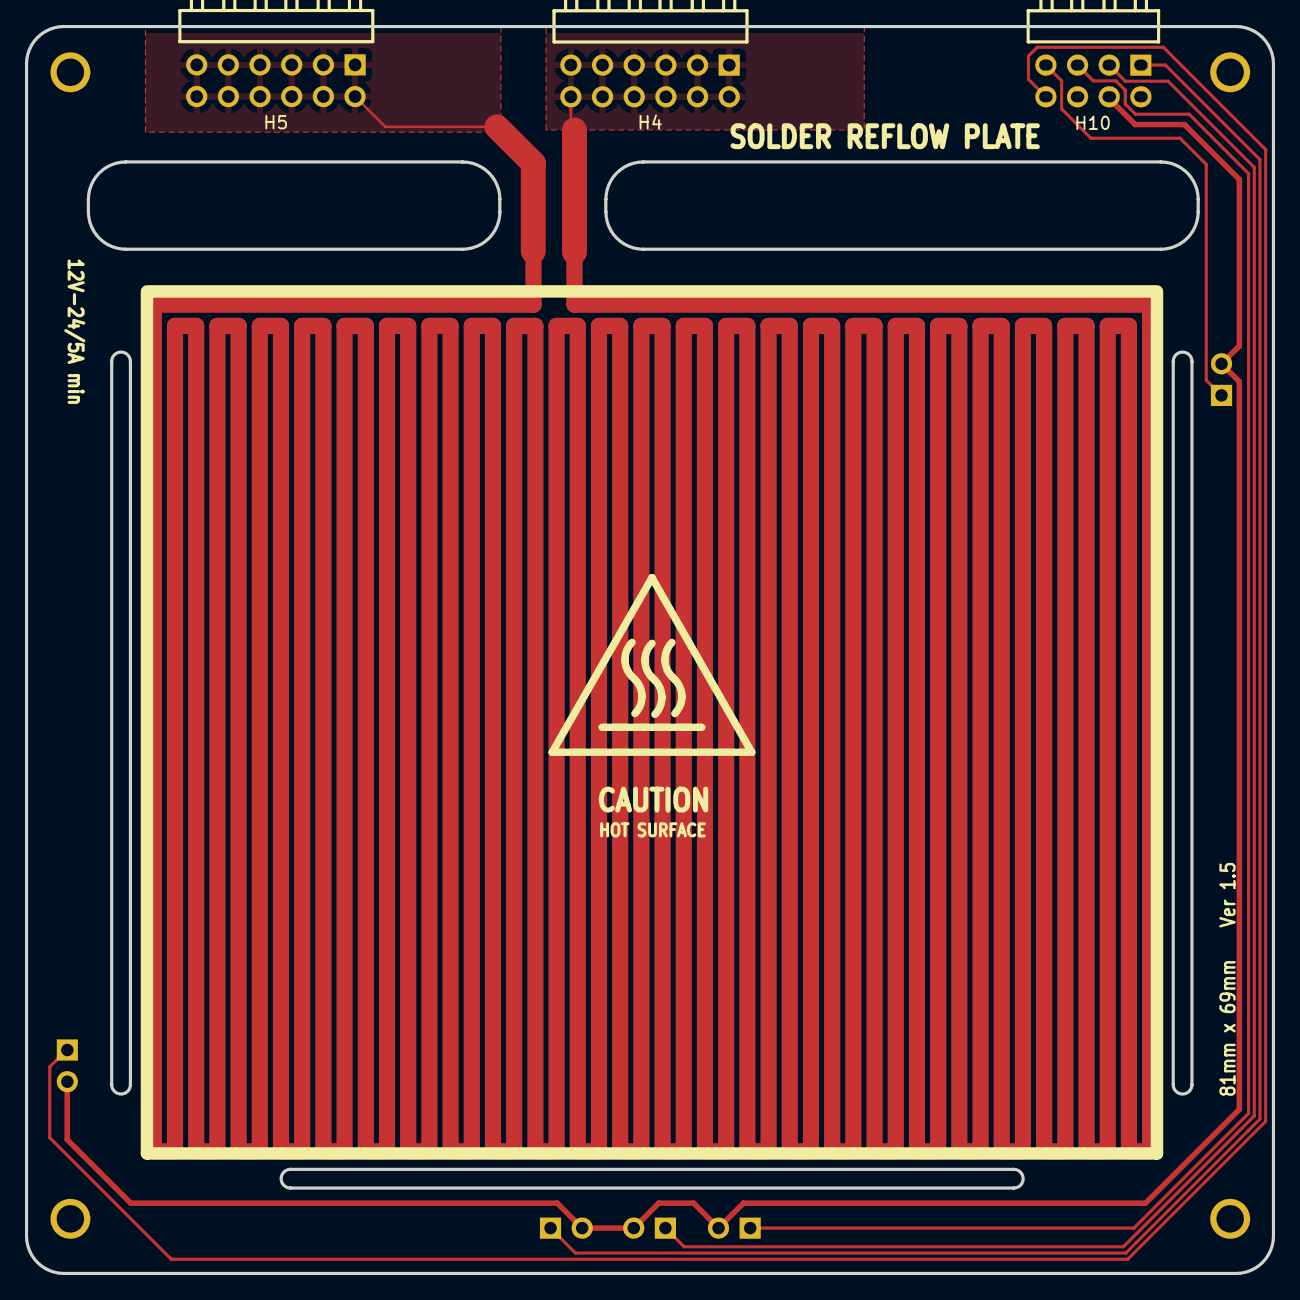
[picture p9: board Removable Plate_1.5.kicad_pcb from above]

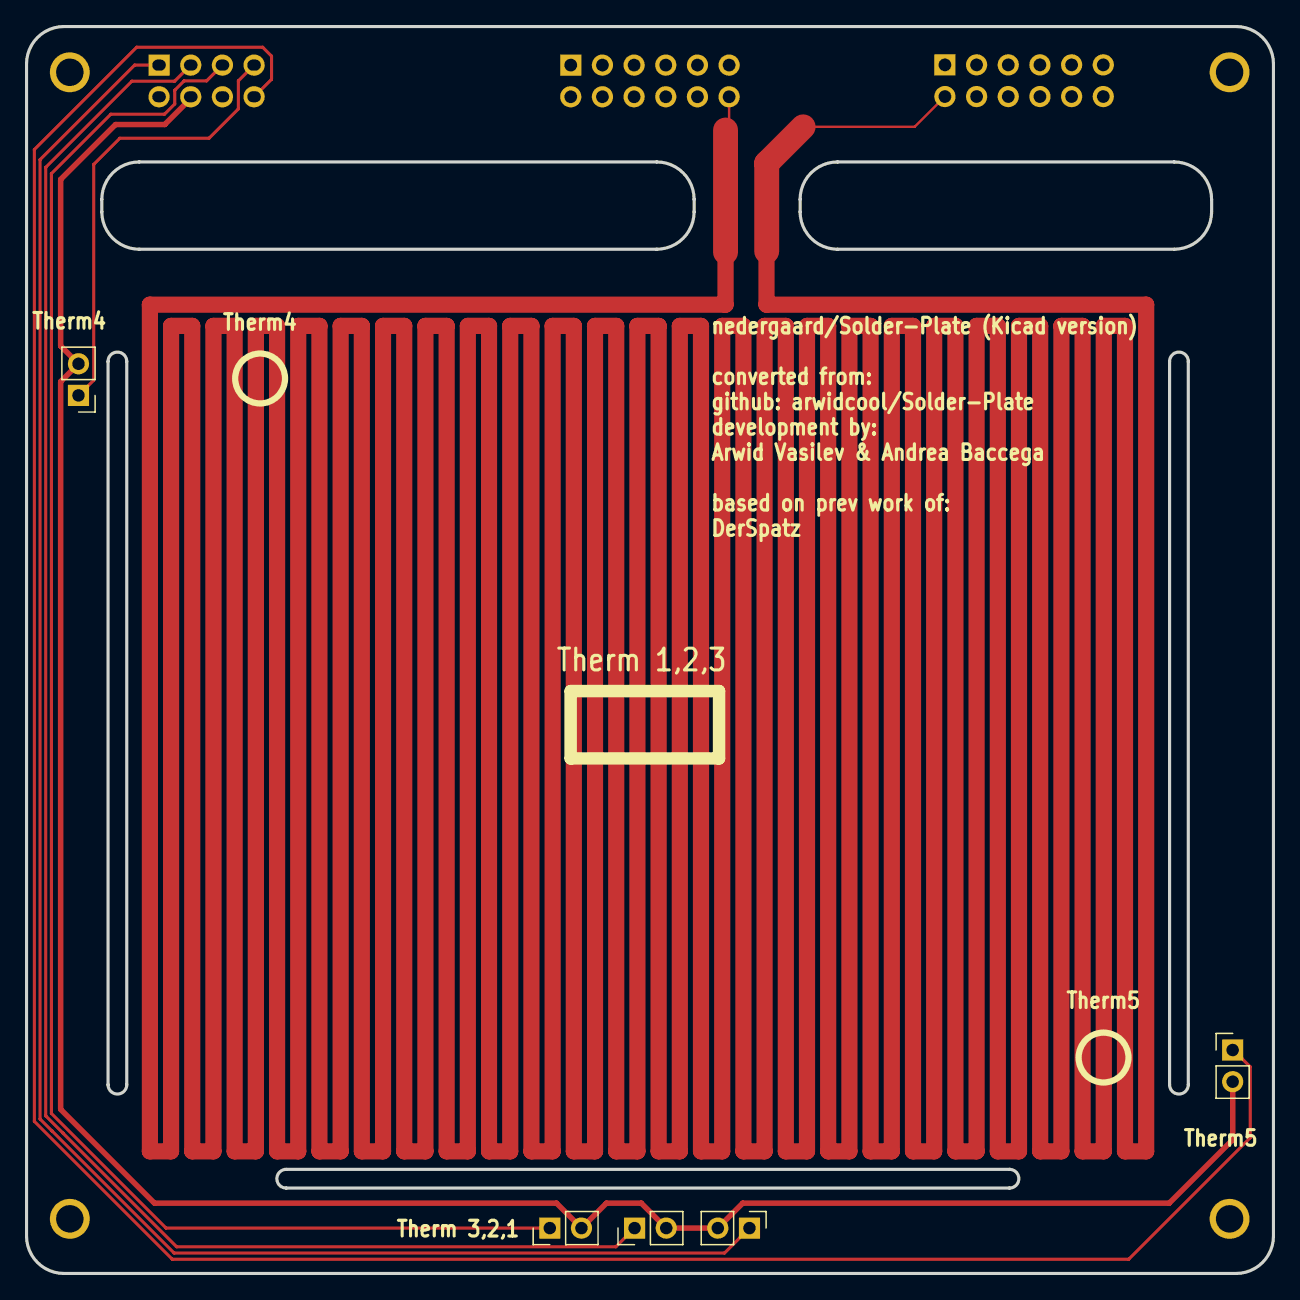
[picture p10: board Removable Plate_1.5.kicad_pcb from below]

Board: 2 copper layers, 100.0 x 100.0 mm, 8 parts (5 on the bottom side), 7 nets.

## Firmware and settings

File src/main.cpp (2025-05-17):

#include <Arduino.h>
#include "ArduPID.h"
#include <Adafruit_GFX.h>
#include <voltageReference/AnalogRef.h>
#include <Wire.h>
#include <thermistors/Thermistor.h>
#include "buttons/Buttons.h"
#include "leds/leds.h"
#include "reflow.h"
#include "displays/oled.h"
#include "displays/tft.h"
#include "PID/PidController.h"
#include "globals.h"
#include "EEPROMDataManager.h"
#include "tools/ExecutionTimer.h"
#include "StopWatch.h"
#include "thermistors/Thermistor.h"
#include "Current/CurrentMonitor.h"

#define MOSTFET_PIN 17

double currentTemp = 0;
double targetTemp = 60;
double pwmValue = 255;

ExecutionTimer executionTimer;

CurrentMonitor currentMonitor = CurrentMonitor();

TemperatureController tempController;

Buttons buttons = Buttons();
LEDS leds = LEDS();
// Declare the PID
ArduPID PID;
OledDisplay oled = OledDisplay();

TFT_Display tftDisplay;

StopWatch thermTimer = StopWatch();
StopWatch thermMilisTimer = StopWatch();

void setup()
{

  pinMode(GATE_PIN, OUTPUT);
  analogWrite(GATE_PIN, 255); // VERY IMPORTANT, DONT CHANGE! 255=off, 0=full power

  Serial.begin(38400);

  // Serial.println("Starting OLED");

  // Set PWM frequency to 64 kHz
  analogWriteFrequency(64);

  buttons.setup();
  leds.setup();
  oled.setup();
  eepromDataManager.setup();

  reflowProcessState.set(ReflowProcessState::USER_INPUT);

  tempController.checkPluggedInThermistors();

  tftDisplay.start();

  thermTimer.setResolution(StopWatch::Resolution::MILLIS);

  thermMilisTimer.setResolution(StopWatch::Resolution::MILLIS);

  Serial.println("Setup done");

  // currentMonitor.calculateMaxPwm();
}
void loop()
{

  //  executionTimer.start();

  // Return the button that changed state
  Pair<ButtonKind, StateChangeEvent<ButtonState>> *k = buttons.handleButtons();
  ReflowProcessState state = reflowProcessState.get();
  if (k != NULL)
  {
    if (state == ReflowProcessState::USER_INPUT)
    {
      leds.handleButtonStateChange(*k);
      oled.handleButtonStateChange(*k);
    }
    else if (state >= ReflowProcessState::PREHEAT && state <= ReflowProcessState::COOL)
    {
      if (k->first == ButtonKind::BACK && k->second.to == ButtonState::PRESSED)
      {
        // STOP REFLOW and restart
        reflowProcessState.set(ReflowProcessState::USER_INPUT);
        pidController.stop();
        leds.reset();
      }
    }
    else if (state == ReflowProcessState::DONE)
    {
      oled.handleButtonStateChange(*k);
    }
  }
  ReflowProcessState newState = reflowProcessState.get();

  if (newState != state)
  {
    debugLine("State changed from " + String(STATE_STR(state)) + " to " + String(STATE_STR(newState)));
    // State changed from state to newState (user input or wifi input needs to be above here)
    if (newState == ReflowProcessState::PREHEAT)
    {

      tftDisplay.init(&chosenReflowProfile);
      tempController.checkPluggedInThermistors();

      chosenReflowProfile.start(tempController.getPlateTemperature());
      // Start the PID
      pidController.start();
      thermMilisTimer.start();
      thermTimer.start();
      // Serial.println("Time,Therm1,Therm2,Therm3,Therm4,Therm5,Therm6,,Scaling1,Scaling2,Scaling3,Scaling4,Scaling5,Scaling6,Averaged1,Weighting1,Weighting2,Weighting3");
    }
  }
  state = newState;

  leds.loop();
  oled.loop();

  if (state >= ReflowProcessState::PREHEAT && state <= ReflowProcessState::COOL)
  {

    pidController.loop();
    pidController.debug();
    float amps = currentMonitor.getSystemCurrentAmps();
    Serial.println("Current: " + String(amps));
    float inVoltage = analogRef.calculateInputVoltage();
    Serial.println("Voltage: " + String(inVoltage));
    // #ifdef DEBUG

    //   #endif

    tftDisplay.drawRealTemp(pidController.getInput(), chosenReflowProfile.getPercentage());
    ReflowStep step = chosenReflowProfile.reflowStep();
    // Here we draw the actual temp vs time to the display

    // if (thermTimer.elapsed() > 1)
    // {

    //   Serial.print(thermTimer.elapsed());
    //   Serial.print(",");
    //   float temp1 = thermistor1.getTemperature();
    //   float temp2 = thermistor2.getTemperature();
    //   float temp3 = thermistor3.getTemperature();
    //   float temp4 = thermistor4.getTemperature();
    //   float temp5 = thermistor5.getTemperature();
    //   float temp6 = thermistor6.getTemperature();
    //   Serial.print(temp1);
    //   Serial.print(",");
    //   Serial.print(temp2);
    //   Serial.print(",");
    //   Serial.print(temp3);
    //   Serial.print(",");
    //   Serial.print(temp4);
    //   Serial.print(",");
    //   Serial.print(temp5);
    //   Serial.print(",");
    //   Serial.print(temp6);
    //   Serial.print(",");
    //   Serial.print(thermistor1.scalingFactor);
    //   Serial.print(",");
    //   Serial.print(thermistor2.scalingFactor);
    //   Serial.print(",");
    //   Serial.print(thermistor3.scalingFactor);
    //   Serial.print(",");
    //   Serial.print(thermistor4.scalingFactor);
    //   Serial.print(",");
    //   Serial.print(thermistor5.scalingFactor);
    //   Serial.print(",");
    //   Serial.print(thermistor6.scalingFactor);
    //   Serial.print(",");

    //   float values[] = {temp2,temp3,temp4};
    //   float weights[] = {thermistor2.getWeightingFactor(),thermistor3.getWeightingFactor(),thermistor4.getWeightingFactor()};
    //   uint8_t length = 3;
    //   float averaged = TemperatureController::getWeightedAverage(values, weights, length);
    //   Serial.print(averaged);
    //   Serial.print(",");
    //   Serial.print(weights[0]);
    //   Serial.print(",");
    //   Serial.print(weights[1]);
    //   Serial.print(",");
    //   Serial.print(weights[2]);
    //   Serial.print(",");
    //   Serial.println();
    // Serial.print(",");
    // Serial.print(thermistor1.getWeightingFactor());
    // Serial.print(",");
    // Serial.print(thermistor2.getWeightingFactor());
    // Serial.print(",");
    // Serial.print(thermistor3.getWeightingFactor());
    // Serial.print(",");
    // Serial.print(thermistor4.getWeightingFactor());
    //}

    if (step.state != newState)
    {
      reflowProcessState.set(step.state);
      if (step.state == ReflowProcessState::DONE)
      {
        pidController.stop();
      }
    }
  }

  //  executionTimer.stop();
}

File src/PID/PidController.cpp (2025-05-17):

#include "PidController.h"
#include "globals.h"
#define GATE_PIN 17
#include "voltageReference/AnalogRef.h"
#include "thermistors/TemperatureController.h"

extern AnalogRef analogRef;

extern TemperatureController tempController;

PidController::PidController(PidControllerData *data)
{

    this->data = data;

    controller.begin(&(this->data->currentTemp), &(this->data->setPoint), &(this->data->targetTemp), PID_P, PID_I, PID_D);
    //  controller.reverse();
    controller.setOutputLimits(PID_OUTPUT_MIN, PID_OUTPUT_MAX);
    controller.setSampleTime(PID_SAMPLE_TIME);
    controller.setWindUpLimits(PID_WINDUP_MIN, PID_WINDUP_MAX);
}

double *PidController::compute()
{

    controller.compute();

    return controller.output;
}

void PidController::debug()
{

    controller.debug(&Serial, " ", PRINT_INPUT |      // Can include or comment out any of these terms to print
                                       PRINT_OUTPUT | // in the Serial plotter
                                       PRINT_SETPOINT | PRINT_BIAS | PRINT_P | PRINT_I | PRINT_D);
}

void PidController::loop()

{
    data->targetTemp = chosenReflowProfile.getTargetTemp();

    // data->currentTemp = thermistor1.getTemperature();

    data->currentTemp = tempController.getPlateTemperature();

    // float sysVoltage = analogRef.calculateSystemVoltage();

    float inVoltage = analogRef.calculateInputVoltage();
    compute();

    // Reverseal of the PWM value is needed because the PID controller is set to work with a normal direction, Creates for a better PID control
    // 255= off, 0=full power
    analogWrite(GATE_PIN, 255 - data->setPoint);
}

void PidController::stop()
{
    data->targetTemp = 0; // should not be needed but why not? --- Its needed it randomly starts again and sometimes goes to heat the plate
                          // STOP --> Always use analog write for sanity- Keep PWM pins labled analogWrite -- Writing it LOW will KEEP IT ON

    analogWrite(GATE_PIN, 255); // VERY IMPORTANT, DONT CHANGE!
    controller.reset();
    controller.stop();
}

void PidController::start()
{
    controller.start();
}

double *PidController::getInput()
{
    return controller.input;
}

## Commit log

2025-04-12 Git ignore KiCad local files
2025-04-12 Added KiCad 9 project for V1.4-Wifi hardware
    [V1.4-Wifi.kicad_pcb, V1.4-Wifi.kicad_sch]
2025-04-12 Marked no-connect as such, except 1
    [V1.4-Wifi.kicad_sch]
2025-04-13 Added custom footprint library
    [V1.4-Wifi.kicad_sch]
2025-04-13 Replaced part C7, C9, C16 from TC212B107M010B to KEMET T491B107M010AT
    [V1.4-Wifi.kicad_pcb, V1.4-Wifi.kicad_sch]
2025-04-13 Git ignore KiCad folders with manual backup zips
2025-04-13 Replaced XH2 connectors with pin headers (CN11-CN16). Added Thermistor 1 to connector. Update 5V symbols with +5V value to inform KiCad about net connection.
    [V1.4-Wifi.kicad_pcb, V1.4-Wifi.kicad_sch]
2025-04-13 Replaced part D1, D6-D8, D10-D11 from MBR0520 to B0520LW-7-F
    [V1.4-Wifi.kicad_pcb, V1.4-Wifi.kicad_sch]
2025-04-13 Removed unused footprints (C2-C5)
    [V1.4-Wifi.kicad_pcb]
2025-04-13 Updated D12,D13 from B5819 to B5819WSL-TP and updated footprint
    [V1.4-Wifi.kicad_pcb, V1.4-Wifi.kicad_sch]
2025-04-13 Replaced part F1 from SMD025F-30 to 1812L050/30PR and updated footprint (1812, smaller)
    [V1.4-Wifi.kicad_pcb, V1.4-Wifi.kicad_sch]
2025-04-13 Replaced part L1 from CDRH74-220MT to VLS6045EX-220M-H and updated footprint. Moved CURRENT_READ trace slightly away from the inductor for noise reasons.
    [V1.4-Wifi.kicad_pcb, V1.4-Wifi.kicad_sch]
2025-04-14 Replaced part LED8-LED11
    [V1.4-Wifi.kicad_sch]
2025-04-14 Replaced part Q1 from AOD4184A to IPD90N04S403
    [V1.4-Wifi.kicad_sch]
2025-04-14 Replaced part Q10 from IRLML2502 to PJA3404A. Updated footprint.
    [V1.4-Wifi.kicad_pcb, V1.4-Wifi.kicad_sch]
2025-04-14 Replaced part Q11 from SI2300 to PJA3404A to simplify BOM. Updated footprint.
    [V1.4-Wifi.kicad_pcb, V1.4-Wifi.kicad_sch]
2025-04-14 Replaced part Q12 from S8050 to BC816-16VL. Updated footprint.
    [V1.4-Wifi.kicad_pcb, V1.4-Wifi.kicad_sch]
2025-04-16 Adjusted resistor value to assist picking correct part by pcb supplier
    [V1.4-Wifi.kicad_sch]
2025-04-17 Moved C2-C5 back in place
    [V1.4-Wifi.kicad_pcb]
2025-04-17 Fixed R and C values manually looking at EasyEDA editor
    [V1.4-Wifi.kicad_pcb, V1.4-Wifi.kicad_sch]
2025-04-19 Updated MPN for updated C parts
    [V1.4-Wifi.kicad_sch]
2025-04-21 Replaced part U2 from AO4409 to DMPH4015SSSQ
    [V1.4-Wifi.kicad_pcb, V1.4-Wifi.kicad_sch]
2025-04-21 Slighty incresed fill areas connected to U2 for heat dissipation
    [V1.4-Wifi.kicad_pcb]
2025-04-21 Replaced U4 from AMS1117-5.0 to LDI1117-05H
    [V1.4-Wifi.kicad_pcb, V1.4-Wifi.kicad_sch]
2025-04-21 Replaced U15 from AMS1117-3.3 to LD1117S33CTR
    [V1.4-Wifi.kicad_pcb, V1.4-Wifi.kicad_sch]
2025-04-27 Upgraded L1 (MSS1048-104MLC) and D7 (SK34SMA-3G). Layout changes to accomodate larger footprints.
    [V1.4-Wifi.kicad_pcb, V1.4-Wifi.kicad_sch]
2025-04-27 Rotated D7 to shorten GND path. Added VIN fill on bu below U16 for heat dissipation.
    [V1.4-Wifi.kicad_pcb]
2025-04-27 Replaced U17 custom footprint with standard
    [V1.4-Wifi.kicad_pcb, V1.4-Wifi.kicad_sch]
2025-04-27 Replaced U18 AtMega footprint with center pad. A bit of rerouting and GND stitching for EMC improvements (shrink GND loops)
    [V1.4-Wifi.kicad_pcb, V1.4-Wifi.kicad_sch]
2025-04-28 Replaced USB1, USB2 to 10118193-0001LF
    [V1.4-Wifi.kicad_pcb, V1.4-Wifi.kicad_sch]
2025-04-28 Replace Buzzer1 with CMT-8504-100-SMT-TR
    [V1.4-Wifi.kicad_pcb, V1.4-Wifi.kicad_sch]
2025-04-28 Cleaned pup symbol table
    [V1.4-Wifi.kicad_sch]
2025-04-28 Reroute (minor), moved via and silkscreen apart, in USB area
    [V1.4-Wifi.kicad_pcb]
2025-04-28 Changed R1,R2 and all 10K resistors to 0805. Fixed comment for C28.
    [V1.4-Wifi.kicad_pcb, V1.4-Wifi.kicad_sch]
2025-04-28 Changed all 4K7 resistors to 0805.
    [V1.4-Wifi.kicad_pcb, V1.4-Wifi.kicad_sch]
2025-04-28 Changed all 1K resistors to 0805. Moved R39 and LED8 a little.
    [V1.4-Wifi.kicad_pcb, V1.4-Wifi.kicad_sch]
2025-04-28 Changed R6-R8,R40-R44,R50,R55 to 0805. Rerouted E_RESET,ESP_BOOT,3.3V. Fixed value of R39,R44
    [V1.4-Wifi.kicad_pcb, V1.4-Wifi.kicad_sch]
2025-04-29 Changed R45,R47,R49-R54 to 0805. Updated value for R41,R55.
    [V1.4-Wifi.kicad_pcb, V1.4-Wifi.kicad_sch]
2025-04-29 Changed via drill to 0.300mm. Default net clearance to 0.1mm. Border to edge 0.3mm. Fixed PCB DRC errors. 2 ignored.
    [V1.4-Wifi.kicad_pcb]
2025-04-29 Removed bom field MPN. Renamed Manufacturer Part to mpn.
    [V1.4-Wifi.kicad_sch]
2025-04-29 Updated R50 to 2K, R6 to 0.33.
    [V1.4-Wifi.kicad_pcb, V1.4-Wifi.kicad_sch]
2025-04-29 Changed R20,22,39 based on LED calculations
    [V1.4-Wifi.kicad_pcb, V1.4-Wifi.kicad_sch]
2025-04-29 Changed C8 to 1205
    [V1.4-Wifi.kicad_pcb, V1.4-Wifi.kicad_sch]
2025-04-30 Added R56 (4K7) and changed R3 to 4K7, to dissipate power safely (slower discharge of caps).
    [V1.4-Wifi.kicad_pcb, V1.4-Wifi.kicad_sch]
2025-04-30 Added R57, changed R7,R8 to make ref voltage divider use E12. Fixed text with formula for Vout in 7.5V Step Down Converter.
    [V1.4-Wifi.kicad_pcb, V1.4-Wifi.kicad_sch]
2025-04-30 Removed R9-R14 pots for thermistor. Added R58-R63 to get good resistor matches for recommended values.
    [V1.4-Wifi.kicad_pcb, V1.4-Wifi.kicad_sch]
2025-04-30 Changed R44 to 2K2, R45 to 3K3 to get a safe conversion from 5V to 3V3 logic (ATMEGA to ESP12)
    [V1.4-Wifi.kicad_pcb, V1.4-Wifi.kicad_sch]
2025-04-30 Filled values for various header parts
    [V1.4-Wifi.kicad_pcb, V1.4-Wifi.kicad_sch]
2025-05-05 Replaced C2-C5 and LED10 (+R21) due to availability.
    [V1.4-Wifi.kicad_pcb, V1.4-Wifi.kicad_sch]
2025-05-10 Tidied up schematics
    [V1.4-Wifi.kicad_sch]
2025-05-10 Replaced Power Jack with screw terminals. Repurposed R3 to bleeder resistor. R1, R53 removed.
    [DG330-5.0-XXP-1Y-00A&Z(H).dxf, V1.4-Wifi.kicad_pcb, V1.4-Wifi.kicad_sch]
2025-05-17 Renamed MOSTFET to GATE_PIN, to align better with schematics.
2025-05-17 Rerouting for tighter return paths for MOSI and SCK. Moved R4,R5 to avoid cutting return path. Renamed LCD_RST, CD, DC to TFT_RST, TFT_CS, TFT_CS to better align with code.
    [V1.4-Wifi.kicad_pcb, V1.4-Wifi.kicad_sch]
2025-05-17 Removed H10 7pin header for TFT, for EMC reasons.
    [V1.4-Wifi.kicad_pcb, V1.4-Wifi.kicad_sch]
2025-05-17 UDPI net shortened and added tight return path.
    [V1.4-Wifi.kicad_pcb]
2025-05-18 I2C_SCL, I2C_SDA return paths tightened
    [V1.4-Wifi.kicad_pcb]
2025-05-18 RXD, TXD return paths tightened
    [V1.4-Wifi.kicad_pcb]
2025-05-18 MEGA_TX, MEGA_RX return paths tightened up
    [V1.4-Wifi.kicad_pcb]
2025-05-20 GATE, FAN_CTRL return paths tightened
    [V1.4-Wifi.kicad_pcb]
2025-05-20 Renamed TFT_LED, TFT_SI_OUT, TFT_SCK_OUT to LCD_* for consistency
    [V1.4-Wifi.kicad_pcb, V1.4-Wifi.kicad_sch]
2025-05-20 E_TX, R_TX return paths tightened
    [V1.4-Wifi.kicad_pcb]
2025-05-21 Cleaning. Simplified segmented traces.
    [V1.4-Wifi.kicad_pcb]
2025-05-24 Moved D8 for EMC reasons. Refactored Fan ctrl schematic. BOM details corrected.
    [V1.4-Wifi.kicad_pcb, V1.4-Wifi.kicad_sch]
2025-05-24 BOM detailes corrected
    [V1.4-Wifi.kicad_pcb, V1.4-Wifi.kicad_sch]
2025-05-24 Changed C27 to T491B107M010AT due to availablility
    [V1.4-Wifi.kicad_pcb, V1.4-Wifi.kicad_sch]
2025-05-24 Moved C27 to avoid disrupting D+_E, D-_E return paths
    [V1.4-Wifi.kicad_pcb]
2025-05-25 Rerouted D+,D-,E_D+,E_D- differential pairs to reduce gap between them. Renamed D+_E, D-_E for KiCad reasons.
    [V1.4-Wifi.kicad_pcb, V1.4-Wifi.kicad_sch]
2025-05-30 Refactor. Visual improvements to PCB layout.
    [V1.4-Wifi.kicad_pcb]
2025-05-31 Added Kicad 9 project for Removable Plate v1.5
    [Removable Plate_1.5.kicad_pcb, Removable Plate_1.5.kicad_sch]
2025-06-05 Refactor. Visual improvements to PCB layout
    [V1.4-Wifi.kicad_pcb]
2025-06-05 Rerouted D+,D-,E_D+,E_D- differential pairs, moving tuning part closer to where the length mismatch occurs
    [V1.4-Wifi.kicad_pcb]
